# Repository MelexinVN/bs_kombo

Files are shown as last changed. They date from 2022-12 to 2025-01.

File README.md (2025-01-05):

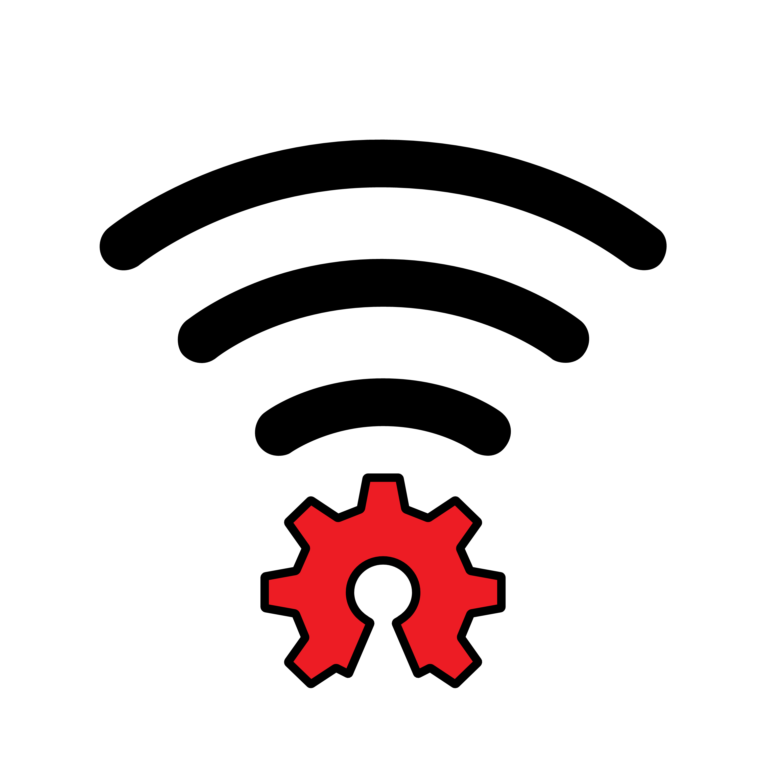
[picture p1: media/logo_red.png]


# Открытые системы беспроводной коммуникации "КомБО"

Беспроводные системы "КомБО" - проект с открытым программным и аппаратным обеспечением 
(Open source hardware)

# Open wireless communication systems "КомБО"

Wireless systems "КомБО" - a project with open software and hardware
(Open source hardware)

## Цели проекта
Целями проекта являются: разработка устройств беспроводной связи различного назначения и свободное распространение результатов этих разработок.

## Project goals
The goals of the project are: development of wireless communication devices for various purposes and free distribution of the results of these developments.

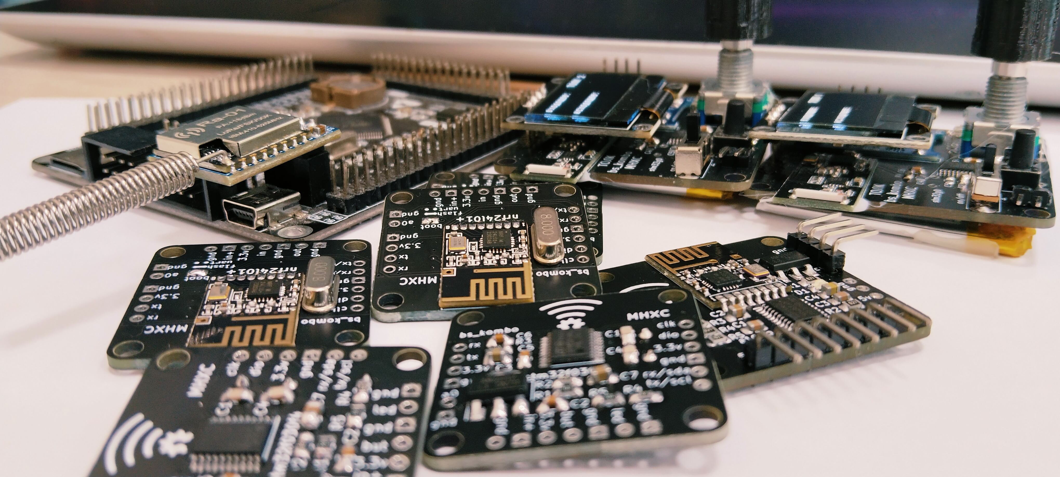
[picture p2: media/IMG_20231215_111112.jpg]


## Основные особенности проекта:
-	***Открытая лицензия***. Все материалы: исходники ПО, проекты печатных плат и 3д модели находятся в свободном доступе. 
-	***Доступные средства разработки***. Используются только бесплатные средства разработки, а также доступные материалы и компоненты.
-	***Подробная документация***. Исходники оформляются максимально подробно и документировано, чтобы их было легко изменить под свои цели. Причем документация преимущественно на русском языке (что, конечно, не принципиально, но для некоторых имеет решающее значение).

## Main features of the project:
- ***Open license***. All materials: software sources, printed circuit board designs and 3D models are freely available.
- ***Available development tools***. Only free development tools are used, as well as available materials and components.
- ***Detailed documentation***. Sources are drawn up in as much detail and documented as possible so that they can be easily changed to suit your purposes. Moreover, the documentation is predominantly in Russian (which, of course, is not essential, but for some it is of decisive importance).

## Прототипы
Ведущие и ведомое устройства собраны на микроконтроллерах ATmega8, ATmega88, ATmega328, STM32F030F4P6, ESP32 и модулях приемо-передатчика NRF24L01+. 
Программы написаны на языке СИ в средах Keil µVision v5, Microchip Studio, а также в среде Arduino IDE специально для платформы Arduino и ESP32.

## Prototypes
Master and slave devices are assembled on ATmega8, ATmega88, ATmega328, STM32F030F4P6, ESP32 microcontrollers and NRF24L01+ transceiver modules.
The programs are written in the SI language in the Keil µVision v5, Microchip Studio environments, as well as in the Arduino IDE specifically for the Arduino and ESP32 platforms.

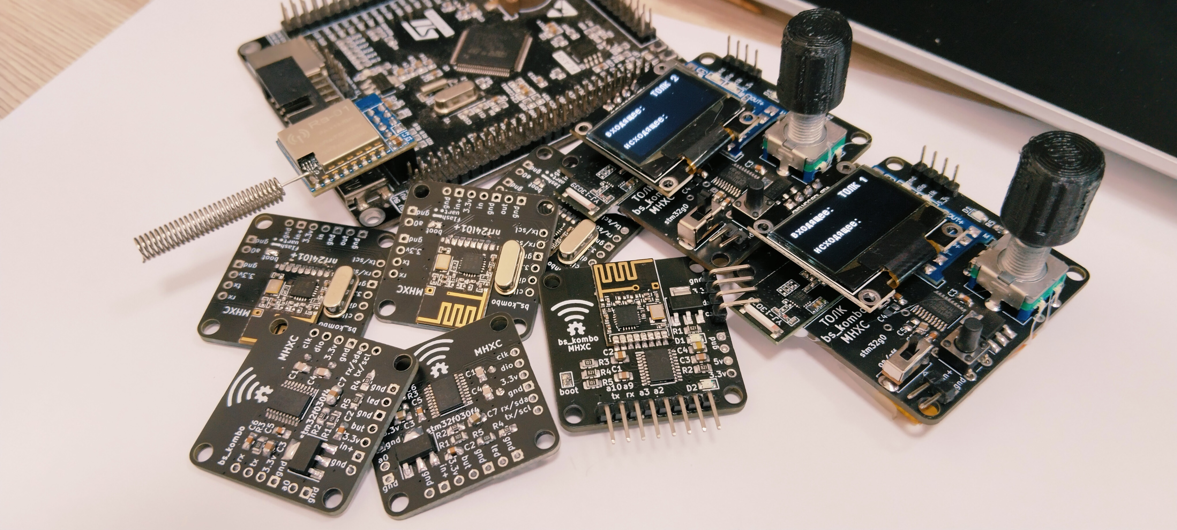
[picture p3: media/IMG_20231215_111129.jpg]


## Содержимое репозитория
### На данный момент в репозитории можно найти:

- исходники программ и исполняемые файлы прошивок устройств;
- исходники печатных плат (проекты в Kicad), а также гербер-файлы для заказа их изготовления;

### Планируется пополнять репозиторий:
- исходниками и STL-файлами новых 3D моделей корпусов;
- специальными программами верхнего уровня для связи с ведущим устройством;
- прошивками и печатными платами для новых исполнений и применений устройств.

## Repository content
### Currently in the repository you can find:

- program sources and executable firmware files for devices;
- sources of printed circuit boards (projects in Kicad), as well as gerber files for ordering their production;

### It is planned to update the repository:
- source codes and STL files of new 3D models of cases;
- special top-level programs for communication with the master device;
- firmware and printed circuit boards for new designs and applications of devices.

## Применения
Первое готовое и оформленное применение проекта - **СИДРУ**



**С**вето-

**И**злучающее

**Д**екоративное

**Р**адиоуправляемое

**У**стройство

Описание структуры, работы, а также все материалы можно найти в [соответствующем репозитории](https://github.com/MelexinVN/bs_kombo_sidru).



## Applications
The first ready and executed application of the project - **СИДРУ**

**Light Emitting Decorative Radio Controlled Device**

A description of the structure, operation, as well as all materials can be found in the [corresponding repository](https://github.com/MelexinVN/bs_kombo_sidru).

### Электронная почта: 		    [bskombo@yandex.ru](bskombo@yandex.ru)

### Социальные сети:

- паблик ВКонтакте: 			  [vk.com/bs_kombo](https://vk.com/bs_kombo)
- Telegram-канал: 	        [t.me/bskombo](https://t.me/bskombo)
- Telegram-чат: 	          [t.me/bs_kombo_chat](https://t.me/bs_kombo_chat)

### Email: [bskombo@yandex.ru](bskombo@yandex.ru)

### Social media:

- public VKontakte: [vk.com/bs_kombo](https://vk.com/bs_kombo)
- Telegram channel: [t.me/bskombo](https://t.me/bskombo)
- Telegram chat: [t.me/bs_kombo_chat](https://t.me/bs_kombo_chat)

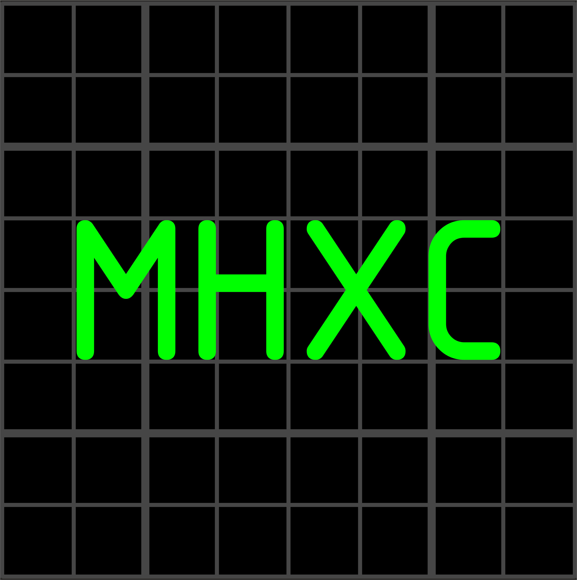
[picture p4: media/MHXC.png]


### Авторы всегда рады отзывам и любым конструктивным предложениям по улучшению проекта! 
### The authors are always happy to receive feedback and any constructive suggestions for improving the project!

## Лицензия
Проект распространяется под лицензией Creative Commons Attribution-ShareAlike 4.0 [CC BY-SA 4.0](https://creativecommons.org/licenses/by-sa/4.0/), 
а программное обеспечение - под лицензией GNU General Public License v3.0 [GPL-3.0 license](https://github.com/MelexinVN/bs_kombo/blob/main/LICENSE)

## License
This project is licensed under the Creative Commons 4.0 license with Attribution-ShareAlike [CC BY-SA 4.0](https://creativecommons.org/licenses/by-sa/4.0/), 
and the software is licensed under the GNU General Public License v3.0 [GPL-3.0 license](https://github.com/MelexinVN/bs_kombo/blob/main/LICENSE)

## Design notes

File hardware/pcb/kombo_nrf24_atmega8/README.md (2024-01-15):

### Плата для МК ATmega8/48/88/168/328 в корпусе TQFP-32 с модулем nrf24l01+ со штырьками.
### 2 слоя.
### Расположение монтажных отверстий сделано под существующие корпуса.

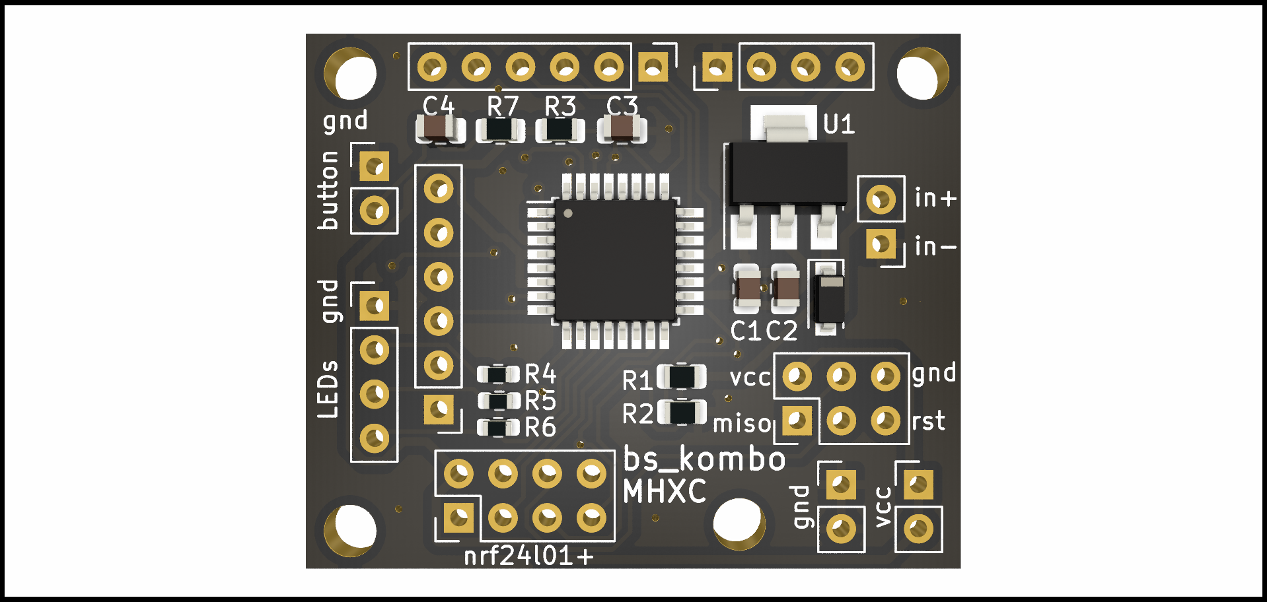
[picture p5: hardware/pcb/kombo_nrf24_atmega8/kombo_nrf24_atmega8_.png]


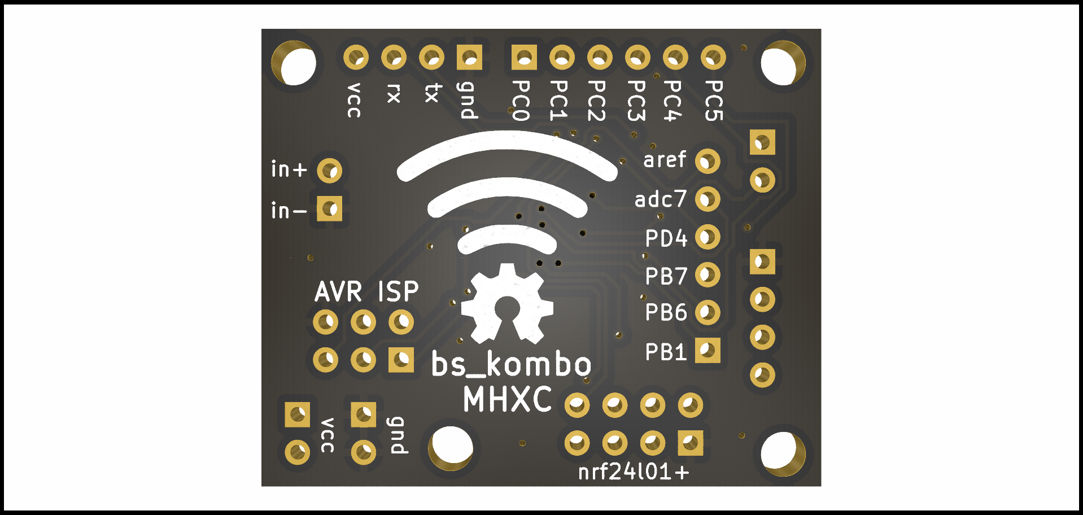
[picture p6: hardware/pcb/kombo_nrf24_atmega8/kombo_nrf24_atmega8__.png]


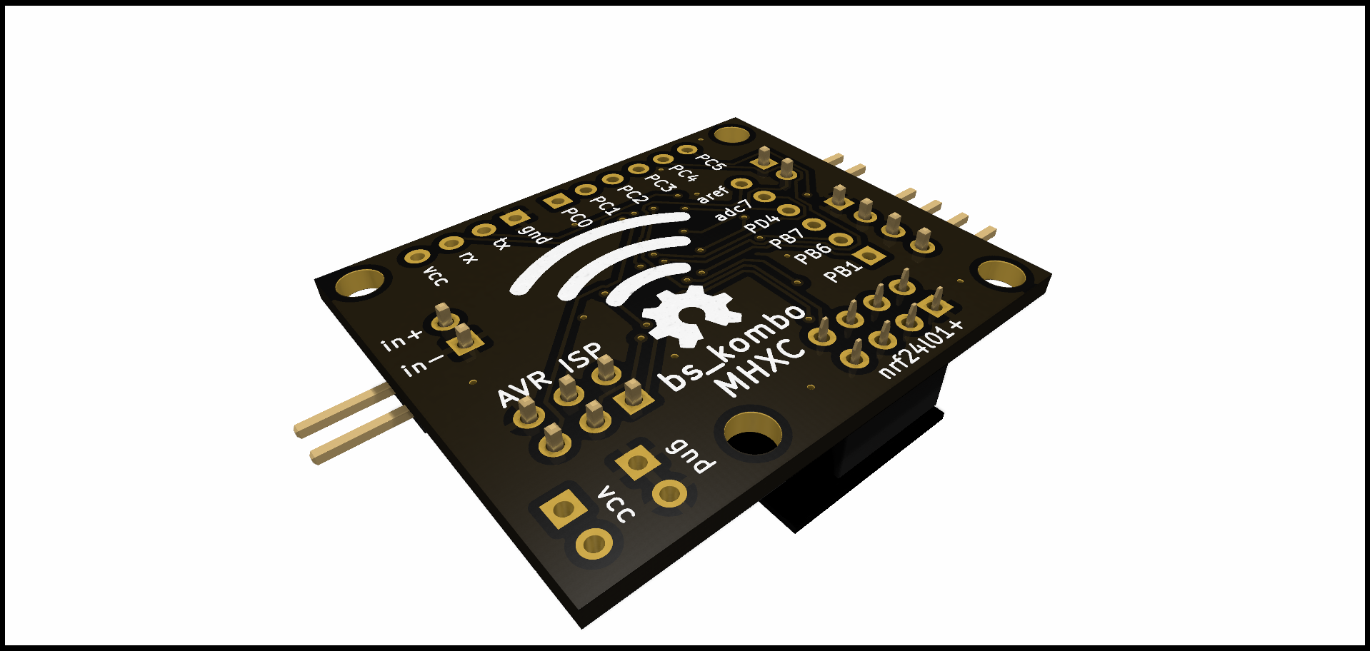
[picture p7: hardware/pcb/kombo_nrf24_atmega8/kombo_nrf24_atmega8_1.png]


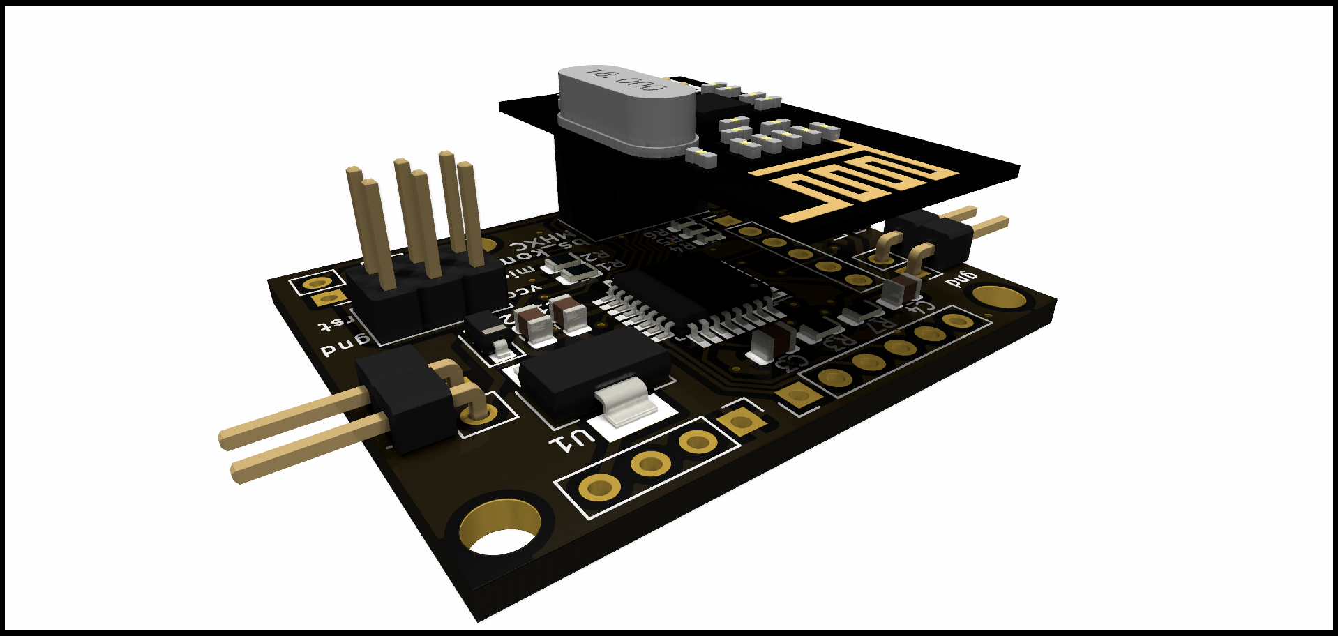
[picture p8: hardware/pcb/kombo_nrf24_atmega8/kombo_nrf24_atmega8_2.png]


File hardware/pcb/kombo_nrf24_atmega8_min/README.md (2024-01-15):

### Плата для МК ATmega8/48/88/168/328 в корпусе TQFP-32 с модулем nrf24l01+ со штырьками.
### Два слоя. Без монтажных отверстий, минимальные габариты - по размеру модуля nrf24l01 в со штырьками.

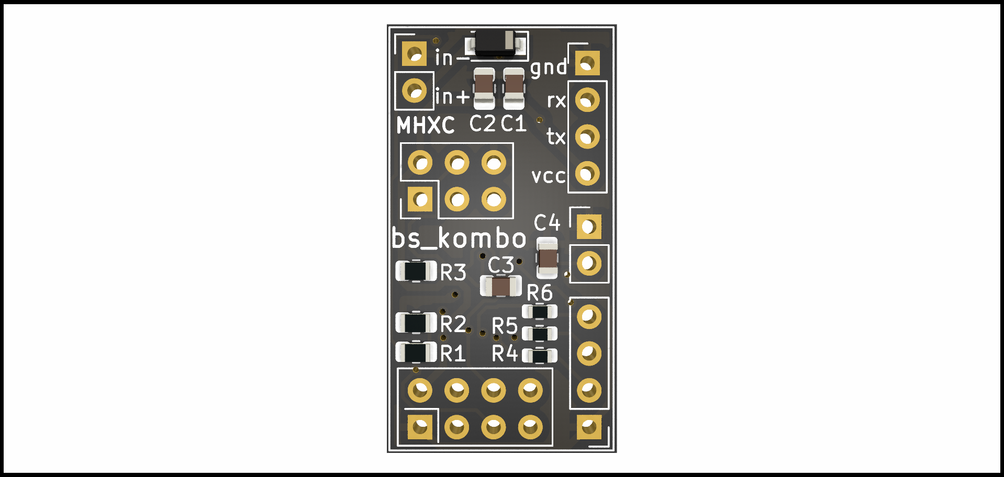
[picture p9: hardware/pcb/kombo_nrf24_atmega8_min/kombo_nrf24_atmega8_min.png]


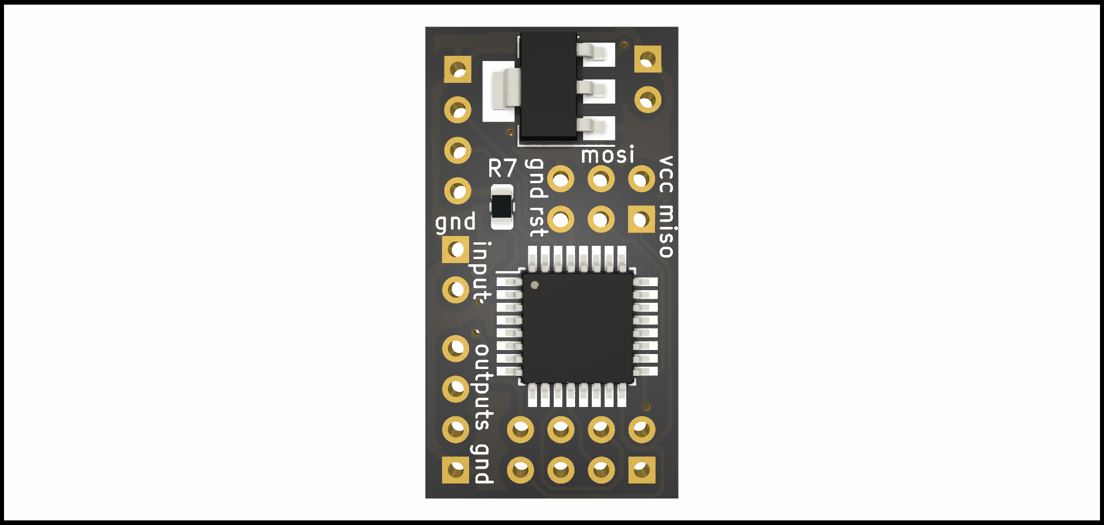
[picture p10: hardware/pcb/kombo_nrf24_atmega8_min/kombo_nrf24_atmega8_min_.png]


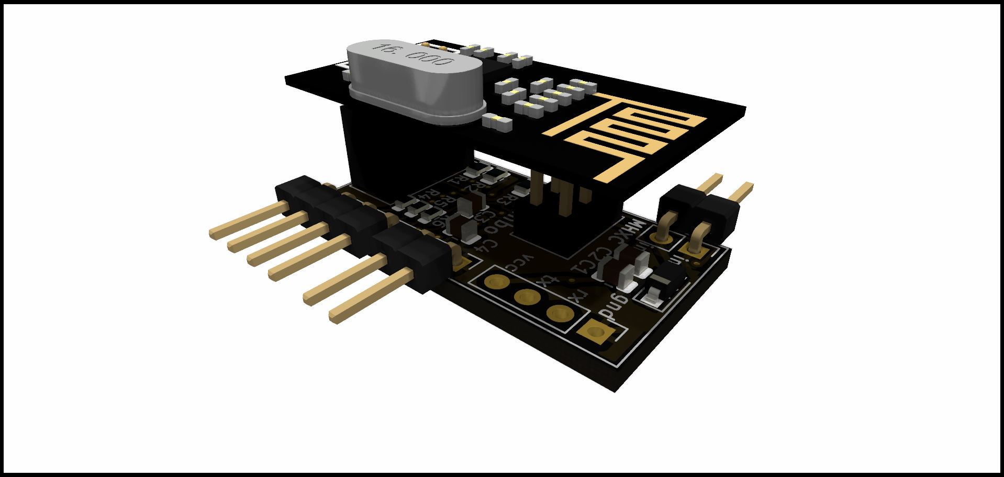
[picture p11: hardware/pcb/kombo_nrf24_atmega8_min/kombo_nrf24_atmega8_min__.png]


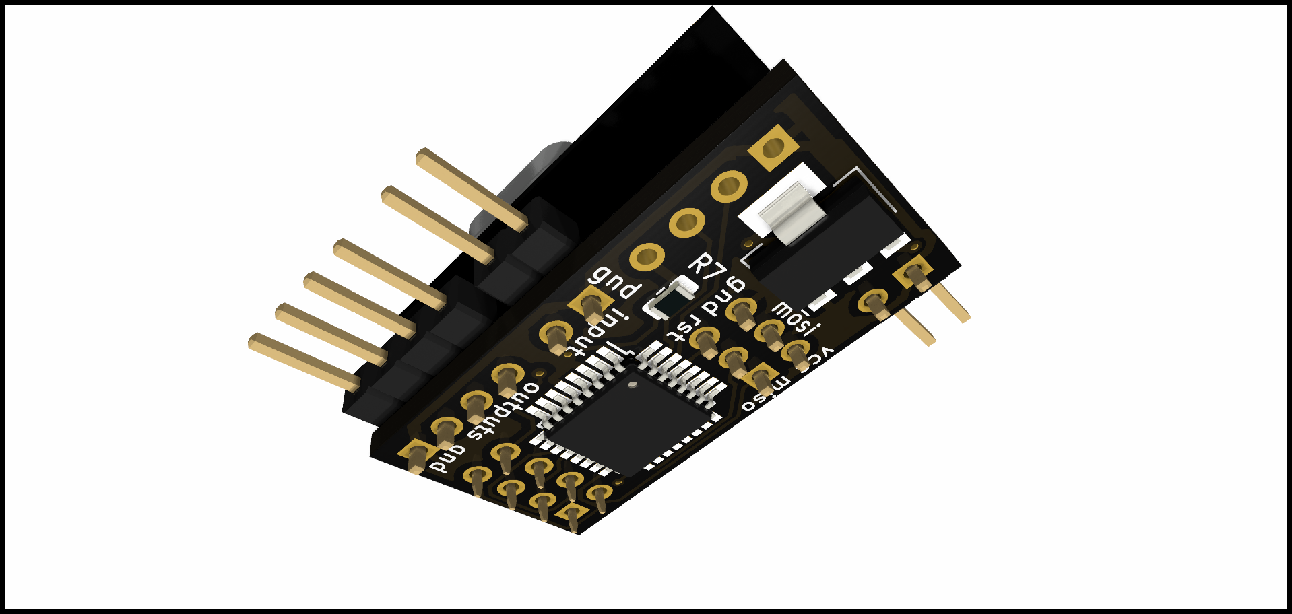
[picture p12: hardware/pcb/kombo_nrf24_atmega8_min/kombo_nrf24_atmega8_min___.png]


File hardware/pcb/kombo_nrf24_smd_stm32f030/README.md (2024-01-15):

### Плата для МК stm32f030f4p6 в корпусе TSSOP-20 с модулем nrf24l01+ в smd исполнении.

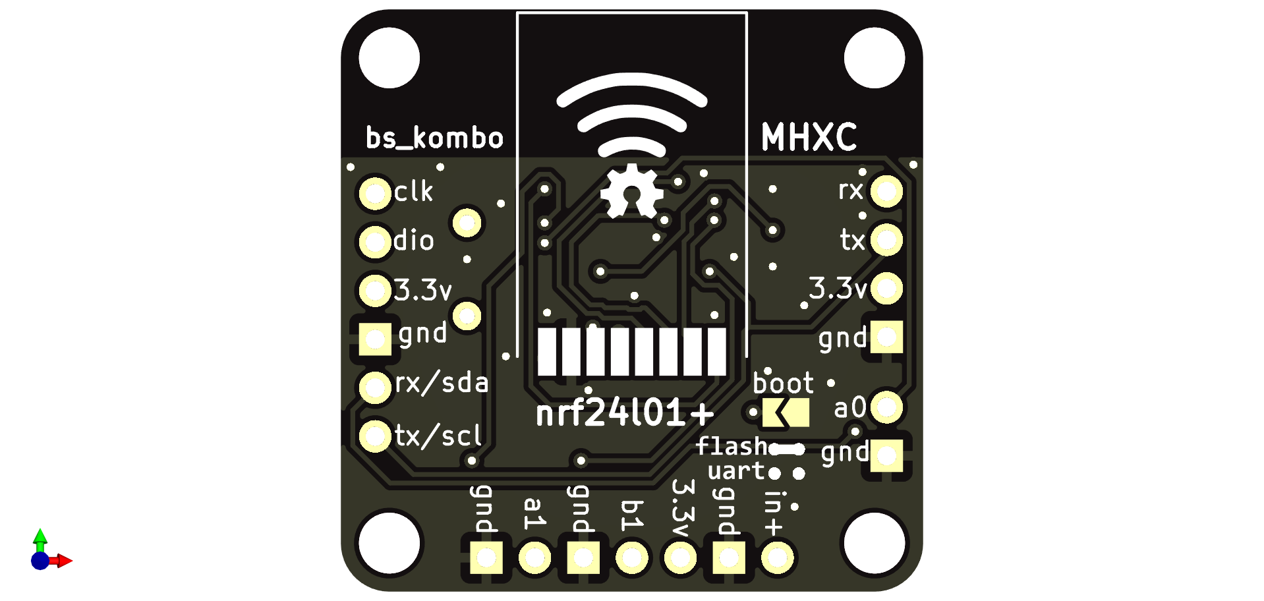
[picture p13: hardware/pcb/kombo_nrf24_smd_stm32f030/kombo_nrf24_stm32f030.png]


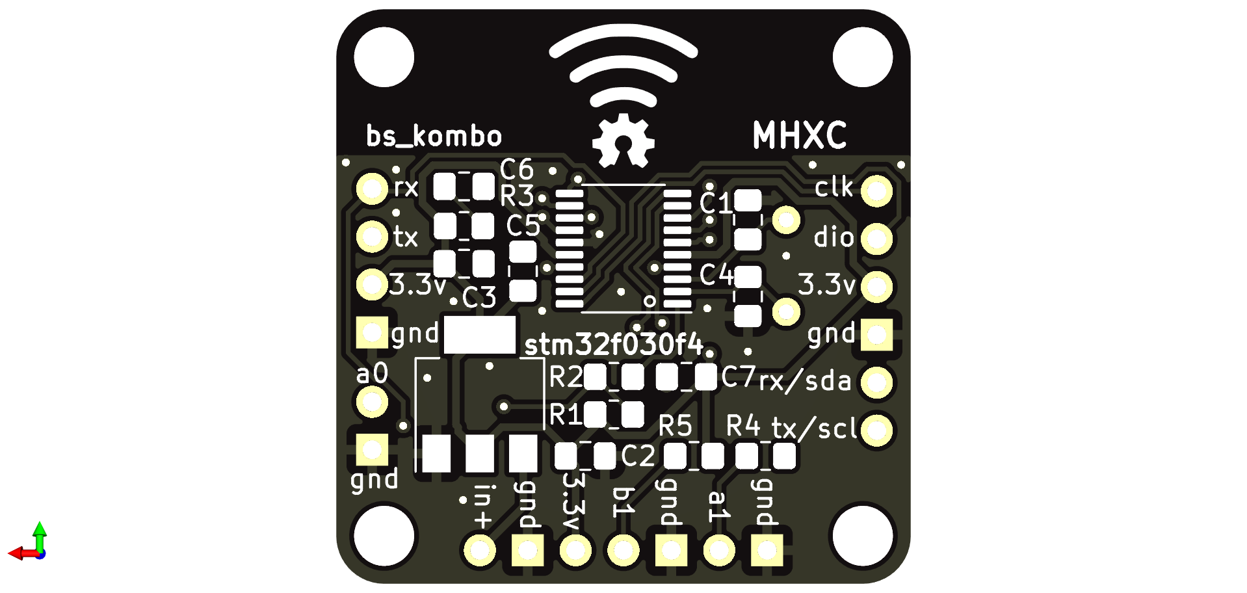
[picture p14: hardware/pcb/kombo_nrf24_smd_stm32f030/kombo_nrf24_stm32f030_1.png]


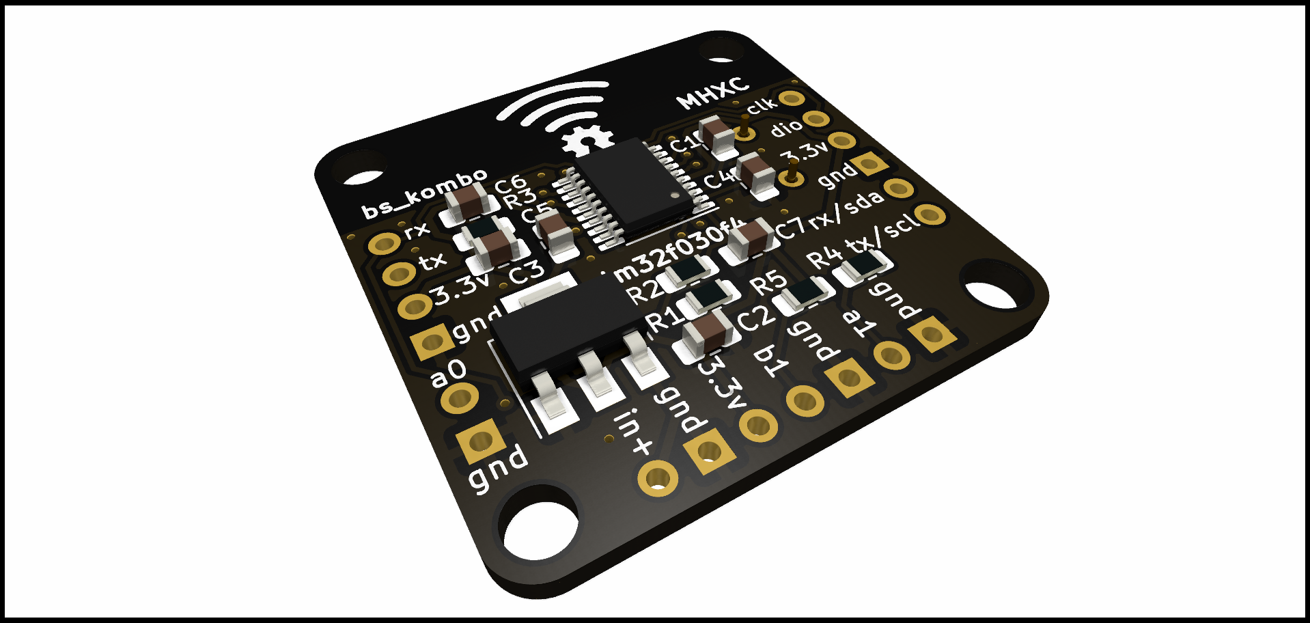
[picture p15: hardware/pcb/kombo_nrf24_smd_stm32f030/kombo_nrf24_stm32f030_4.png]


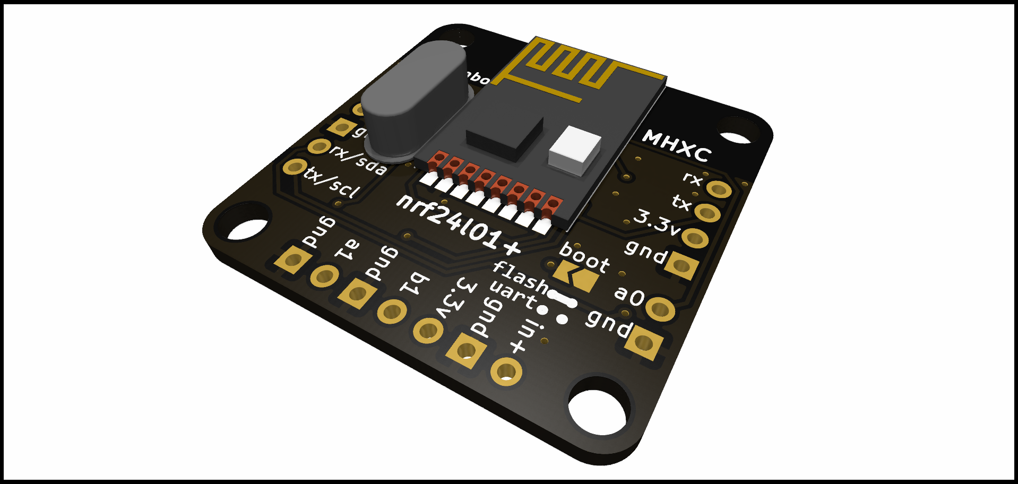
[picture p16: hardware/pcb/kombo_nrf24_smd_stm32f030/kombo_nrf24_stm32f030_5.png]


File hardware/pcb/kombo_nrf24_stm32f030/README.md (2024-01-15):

### Плата для МК stm32f030f4p6 в корпусе TSSOP-20 с модулем nrf24l01+ со штырьками.

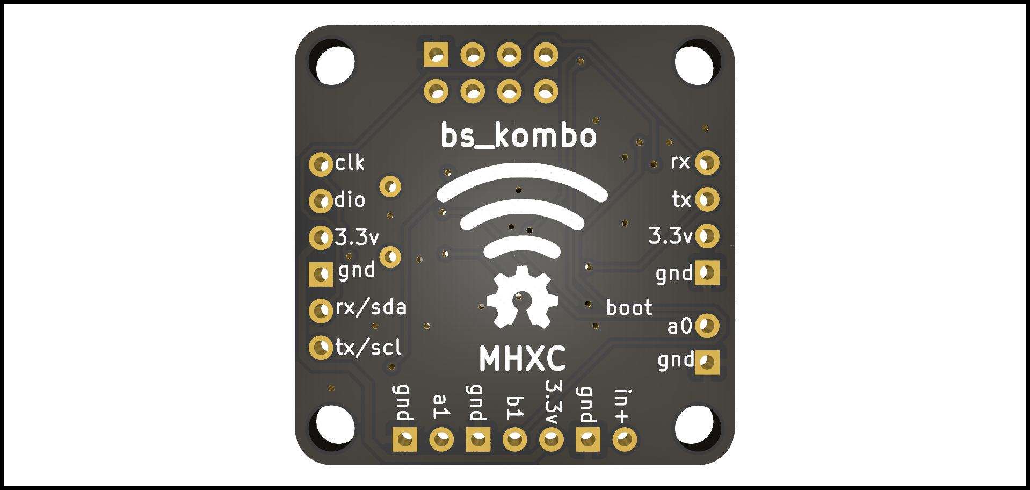
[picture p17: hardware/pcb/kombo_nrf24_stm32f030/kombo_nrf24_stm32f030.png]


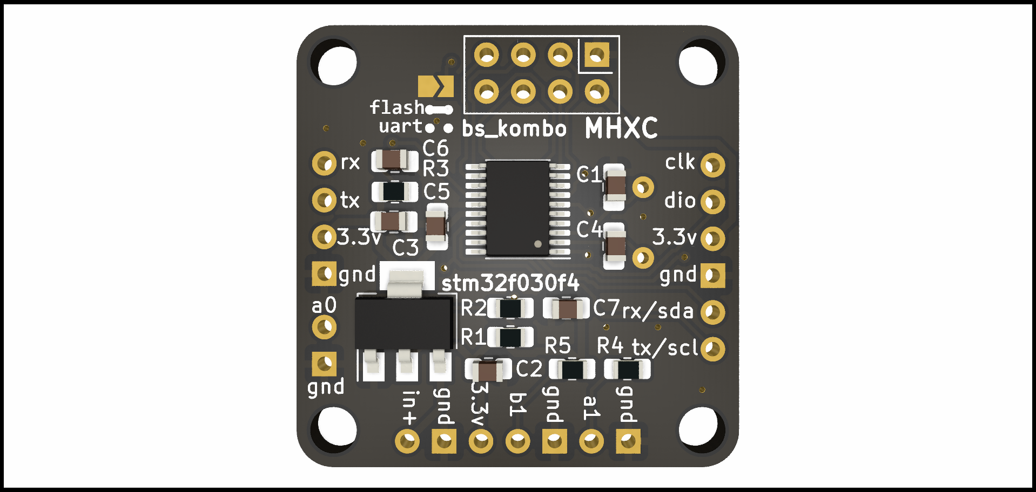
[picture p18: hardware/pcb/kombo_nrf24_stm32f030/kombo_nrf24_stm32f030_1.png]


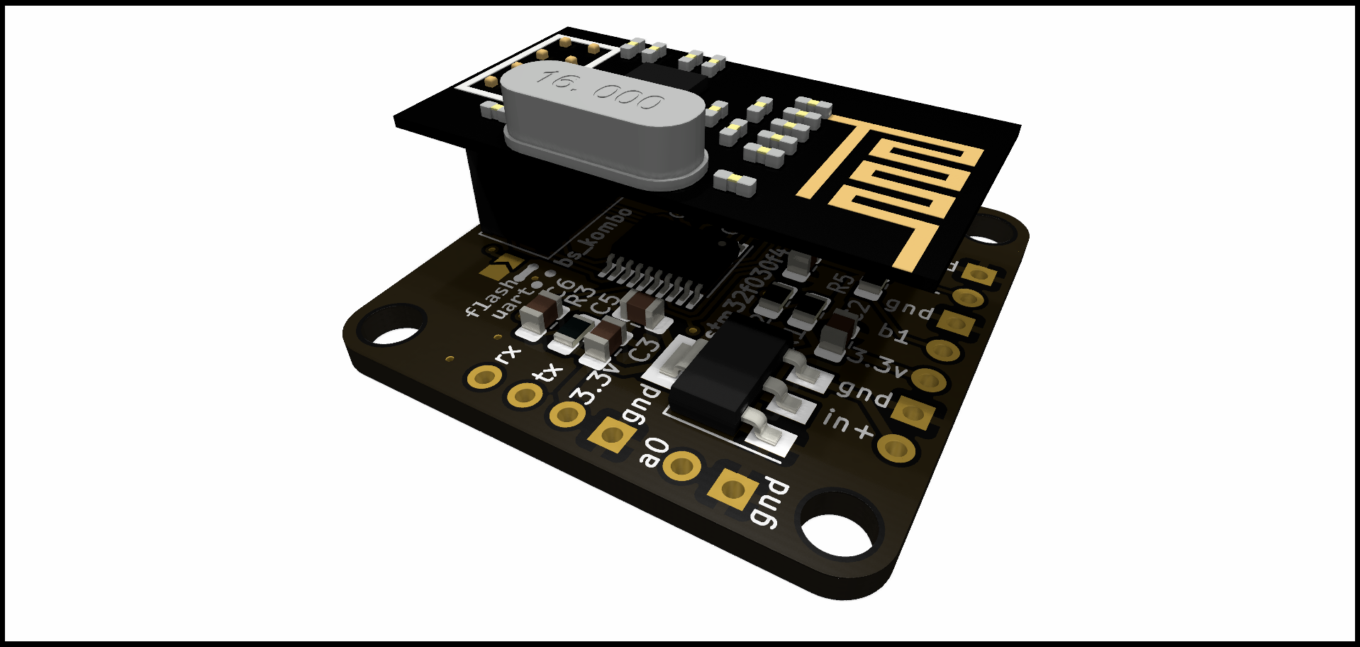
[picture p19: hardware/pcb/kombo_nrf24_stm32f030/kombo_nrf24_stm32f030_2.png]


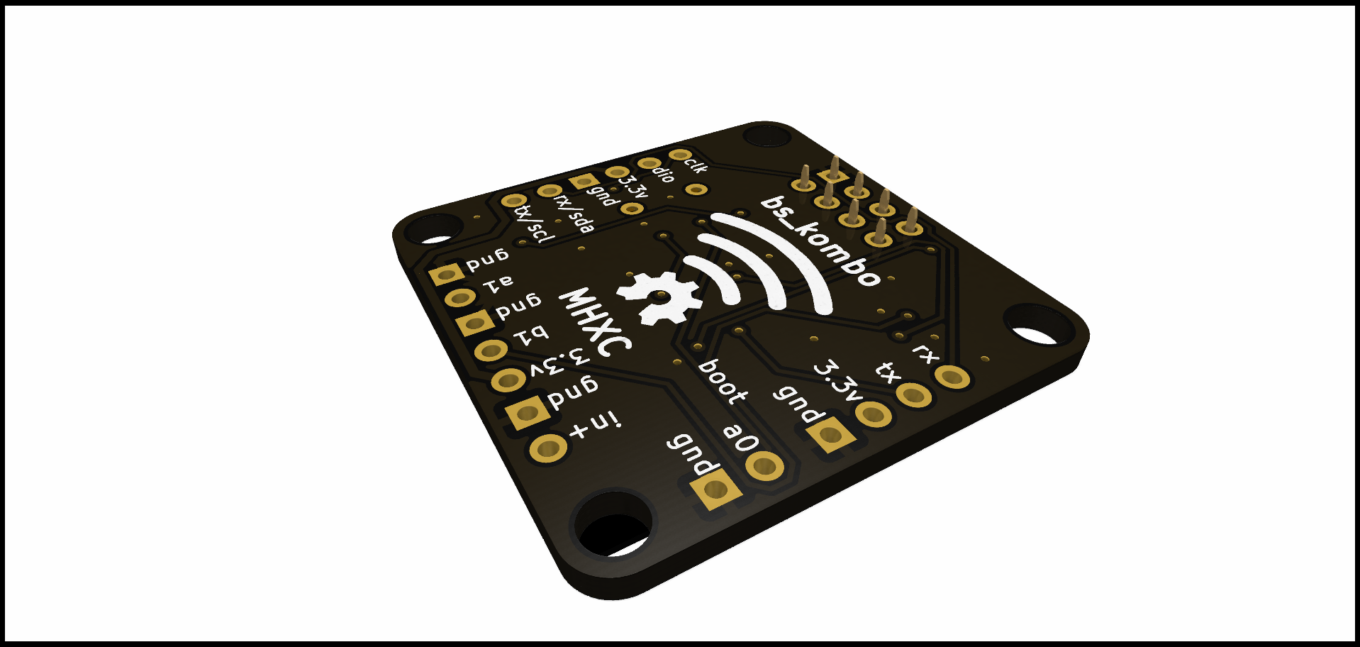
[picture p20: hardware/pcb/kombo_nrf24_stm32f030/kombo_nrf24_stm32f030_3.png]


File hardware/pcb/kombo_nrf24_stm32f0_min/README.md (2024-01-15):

### Плата для МК stm32f030f4p6 в корпусе TSSOP-20 с модулем nrf24l01+ со штырьками.
### Два слоя. Без монтажных отверстий, минимальные габариты - по размеру модуля nrf24l01 в со штырьками.

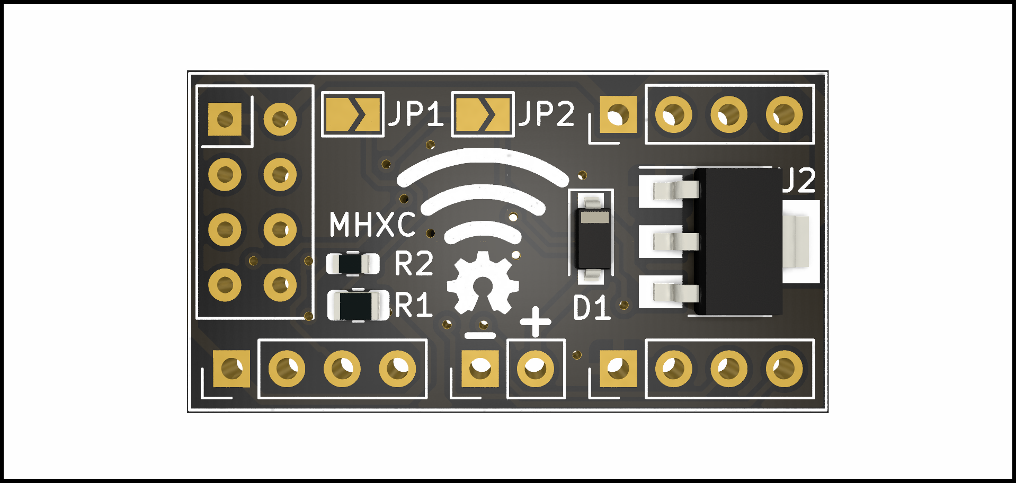
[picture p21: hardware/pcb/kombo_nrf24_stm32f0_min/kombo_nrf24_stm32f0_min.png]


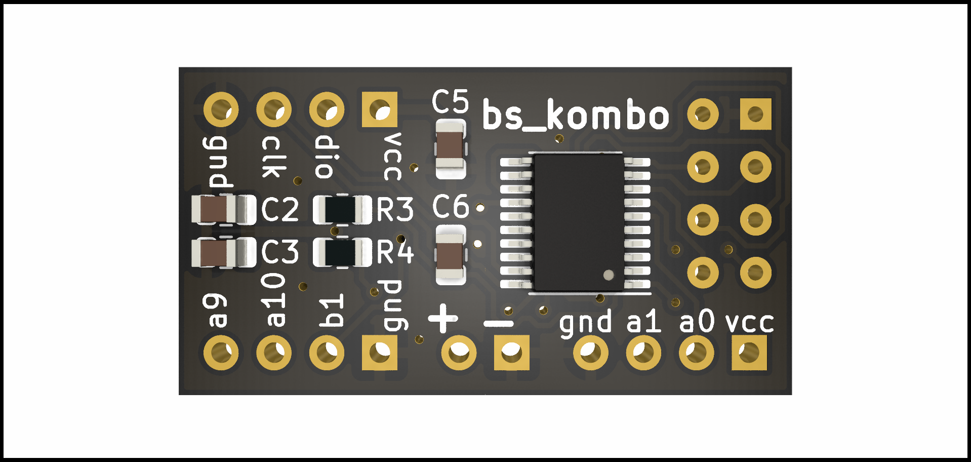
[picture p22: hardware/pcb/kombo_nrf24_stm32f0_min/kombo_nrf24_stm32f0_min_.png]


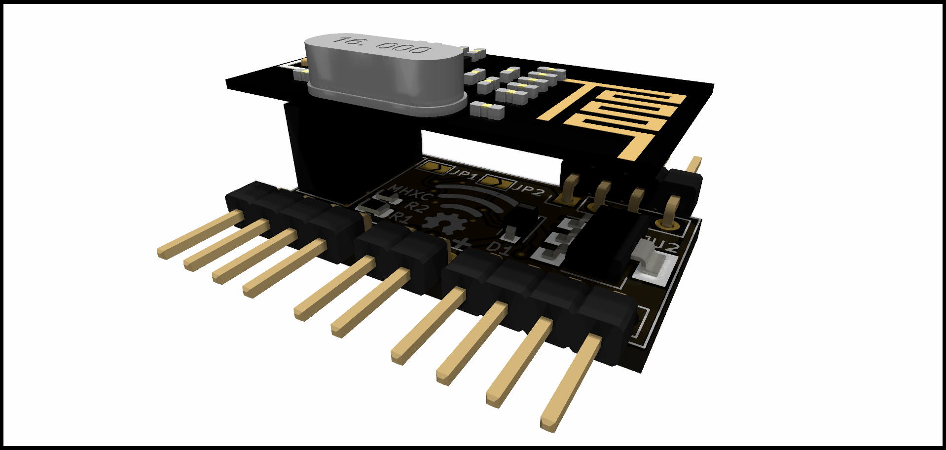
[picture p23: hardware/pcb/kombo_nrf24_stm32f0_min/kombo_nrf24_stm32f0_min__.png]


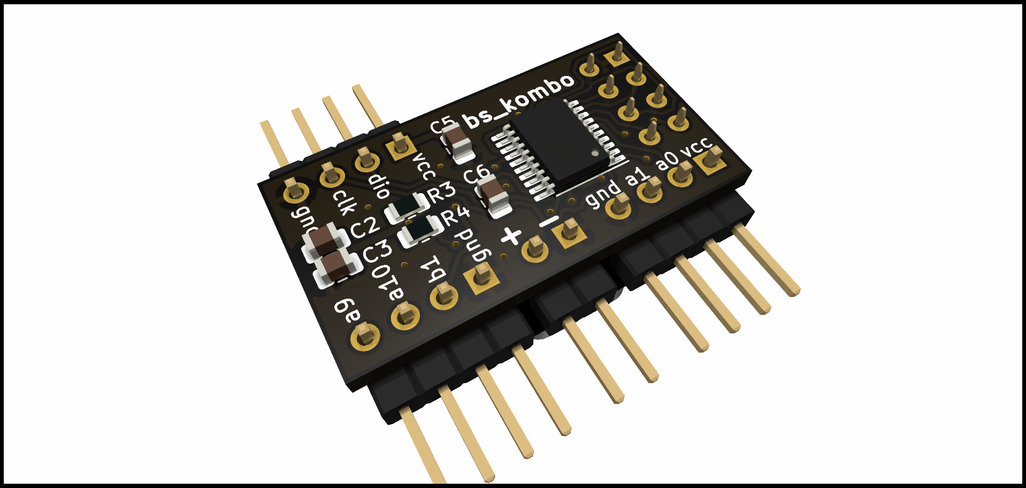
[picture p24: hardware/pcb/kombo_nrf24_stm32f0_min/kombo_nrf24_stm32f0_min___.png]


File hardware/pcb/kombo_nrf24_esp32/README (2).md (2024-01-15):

### Плата для ESP32-WROOM с smd модулем nrf24l01+.
### Для перевода в режим загрузки прошивки нажать кнопку "EN" и отпустить при зажатой кнопке "BOOT", либо подать питание при зажатой кнопке "BOOT".

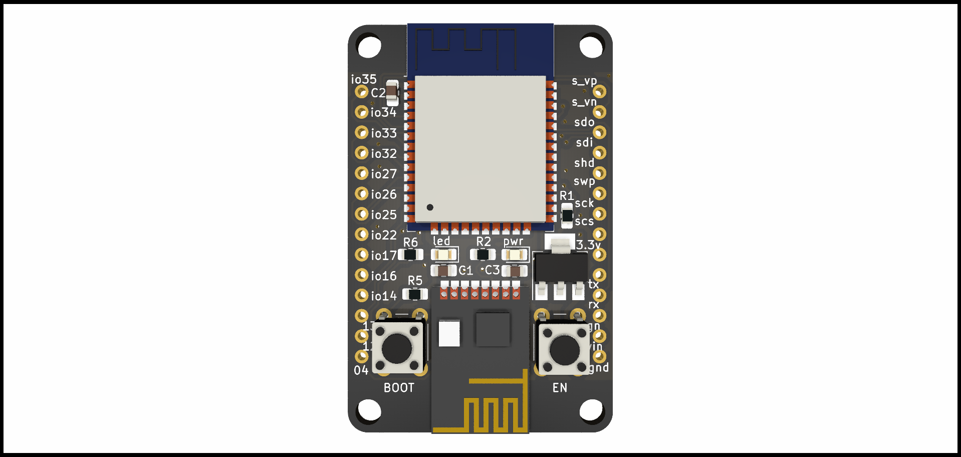
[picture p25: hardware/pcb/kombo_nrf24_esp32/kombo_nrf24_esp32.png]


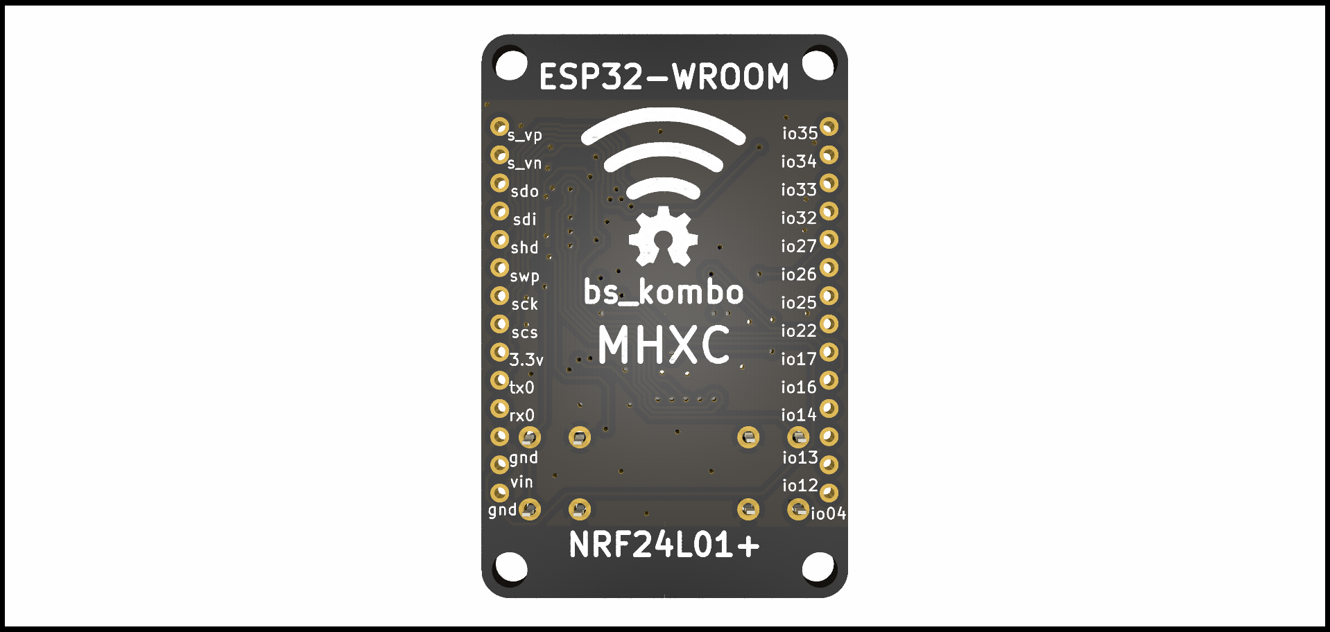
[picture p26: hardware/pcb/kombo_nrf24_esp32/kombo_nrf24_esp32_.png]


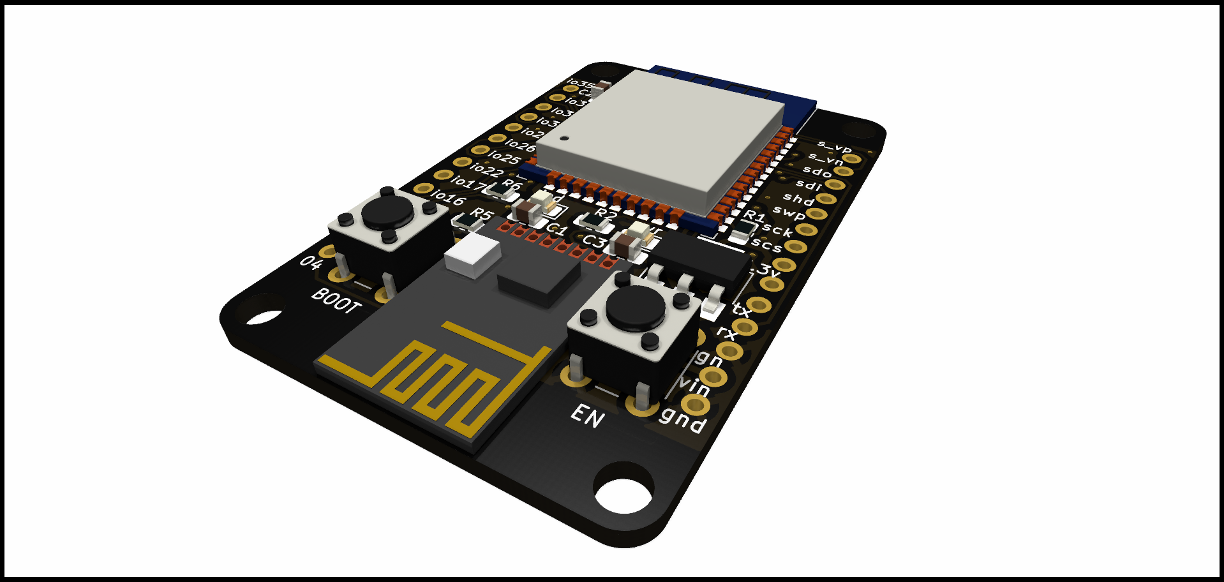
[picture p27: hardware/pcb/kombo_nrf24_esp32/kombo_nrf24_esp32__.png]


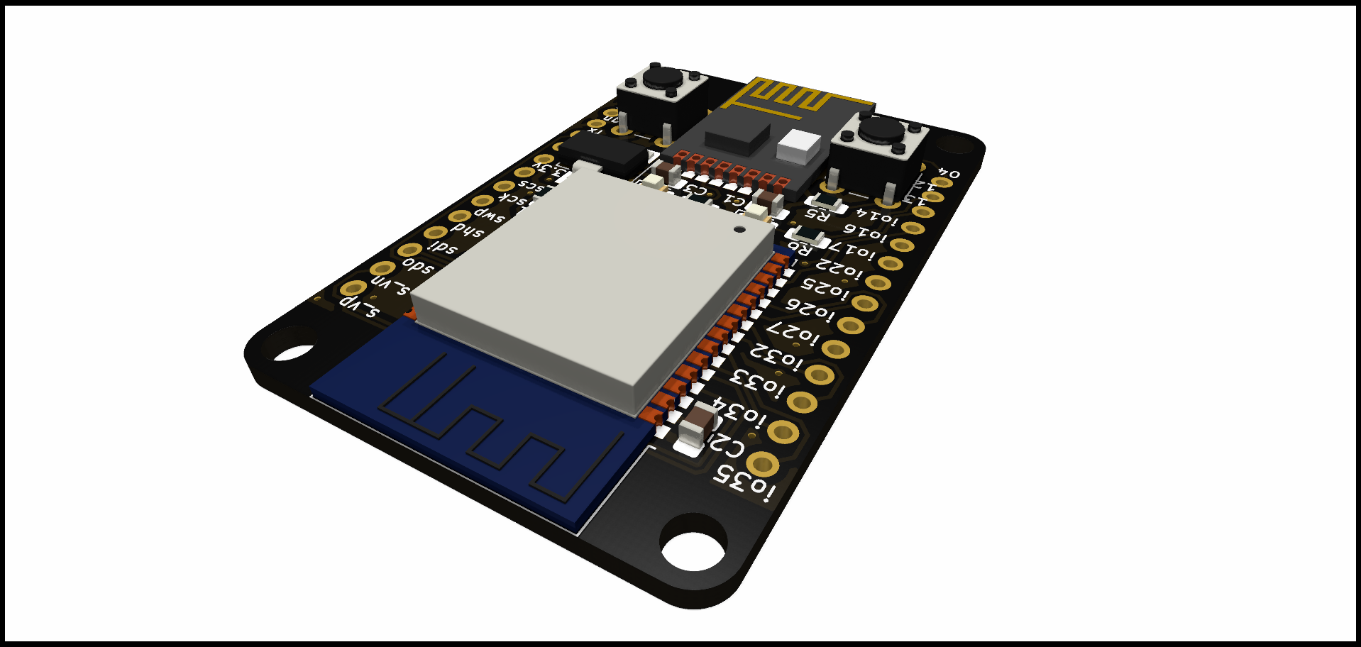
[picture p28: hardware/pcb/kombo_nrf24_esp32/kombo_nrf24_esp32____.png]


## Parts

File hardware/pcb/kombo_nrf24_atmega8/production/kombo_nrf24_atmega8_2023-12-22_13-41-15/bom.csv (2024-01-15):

Designator | Footprint | Quantity | Value | LCSC Part #
C1, C3, C4 | 0805 | 3 | 100n
C2 | 0805 | 1 | 10u
D1 | D_SOD-123 | 1 | 1N4148W
J1, J7, J8, J9 | PinHeader_1x02_P2.54mm_Vertical | 4 | Conn_01x02
J2, J4 | PinHeader_1x06_P2.54mm_Vertical | 2 | Conn_01x06
J3 | PinHeader_2x03_P2.54mm_Vertical | 1 | AVR-ISP-6
J5, J6 | PinHeader_1x04_P2.54mm_Vertical | 2 | Conn_01x04
R1, R2 | 0805 | 2 | 4,7k
R3, R7 | 0805 | 2 | 10k
R4, R5, R6 | 0603 | 3 | 620
U1 | SOT-223-3_TabPin2 | 1 | AMS1117-3.3
U2 | TQFP-32_7x7mm_P0.8mm | 1 | ATmega8A-A
U3 | PinHeader_2x04_P2.54mm_Vertical | 1 | NRF24L01_Breakout

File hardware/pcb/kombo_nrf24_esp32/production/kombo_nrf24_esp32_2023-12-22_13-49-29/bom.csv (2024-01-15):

Designator | Footprint | Quantity | Value | LCSC Part #
C1 | 0805 | 1 | 100n
C2, C3 | 0805 | 2 | 10u
D1, D2 | 0805 | 2 | LED
J1 | PinHeader_1x02_P2.54mm_Vertical | 1 | Conn_01x02
J2 | PinHeader_1x08_P2.54mm_Vertical | 1 | Conn_01x08
J3 | PinHeader_1x04_P2.54mm_Vertical | 1 | Conn_01x04
J4 | PinHeader_1x14_P2.54mm_Vertical | 1 | Conn_01x14
R1, R5 | 0805 | 2 | 10К
R2, R6 | 0805 | 2 | 620
SW1, SW2 | SW_PUSH_6mm_H4.3mm | 2 | SW_Push_Dual_x2
U1 | SOT-223-3_TabPin2 | 1 | AMS1117-3.3
U2 | ESP32-WROOM-32 | 1 | ESP32-WROOM-32
U3 | NRF24L01-SMD | 1 | NRF24L01_Breakout

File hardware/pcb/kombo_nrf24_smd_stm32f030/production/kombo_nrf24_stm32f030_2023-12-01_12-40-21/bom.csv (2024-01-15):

Designator | Footprint | Quantity | Value | LCSC Part #
C1, C4 | 0805 | 2 | 22p
C2, C5, C6 | 0805 | 3 | 100n
C3, C7 | 0805 | 2 | 10u
J1 | PinHeader_1x07_P2.54mm_Vertical | 1 | Conn_01x07
J2 | PinHeader_1x04_P2.54mm_Vertical | 1 | Conn_01x04
J3 | PinHeader_1x06_P2.54mm_Vertical | 1 | Conn_01x06
J4 | PinHeader_1x02_P2.54mm_Vertical | 1 | Conn_01x02
JP1 | SolderJumper-2_P1.3mm_Open_TrianglePad1.0x1.5mm | 1 | SolderJumper_2_Open
R1, R3, R5 | 0805 | 3 | 10k
R2, R4 | 0805 | 2 | 620
U1 | NRF24L01-Module-SMD | 1 | NRF24L01_Breakout
U2 | SOT-223-3_TabPin2 | 1 | AMS1117-3.3
U3 | TSSOP-20_4.4x6.5mm_P0.65mm | 1 | STM32F030F4Px
Y1 | Crystal_HC49-U_Vertical | 1 | Crystal

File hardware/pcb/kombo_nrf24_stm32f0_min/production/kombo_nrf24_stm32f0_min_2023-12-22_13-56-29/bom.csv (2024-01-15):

Designator | Footprint | Quantity | Value | LCSC Part #
C2, C5, C6 | 0805 | 3 | 100n
C3 | 0805 | 1 | 10u
D1 | D_SOD-123 | 1 | 1N4148W
J1 | PinHeader_1x02_P2.54mm_Vertical | 1 | Conn_01x02
J2, J3, J4 | PinHeader_1x04_P2.54mm_Vertical | 3 | Conn_01x04
JP1, JP2 | SolderJumper-2_P1.3mm_Open_TrianglePad1.0x1.5mm | 2 | SolderJumper_2_Open
R1, R3 | 0805 | 2 | 10k
R2 | 0603 | 1 | 620
R4 | 0805 | 1 | 4,7k
U1 | nRF24L01_Breakout | 1 | NRF24L01_Breakout
U2 | SOT-223-3_TabPin2 | 1 | AMS1117-3.3
U3 | TSSOP-20_4.4x6.5mm_P0.65mm | 1 | STM32F030F4Px

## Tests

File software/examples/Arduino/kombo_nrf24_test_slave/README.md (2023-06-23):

## Пример создан в версии Arduino IDE v.2.0.3

### Вариант подключения:

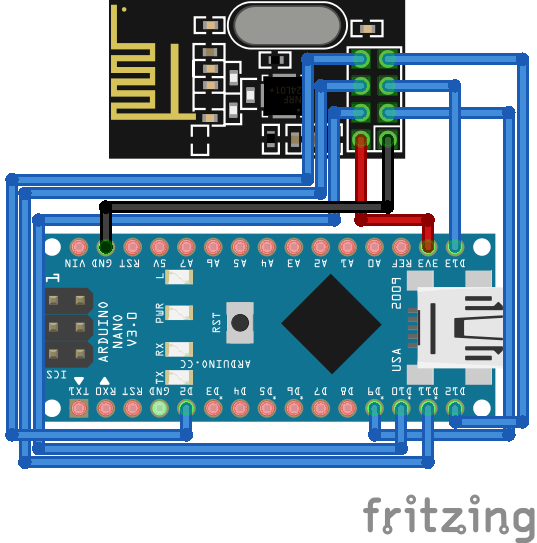
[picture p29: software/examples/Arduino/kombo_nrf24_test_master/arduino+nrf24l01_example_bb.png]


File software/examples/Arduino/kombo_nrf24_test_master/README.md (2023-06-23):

## Пример создан в версии Arduino IDE v.2.1.0

### Вариант подключения:



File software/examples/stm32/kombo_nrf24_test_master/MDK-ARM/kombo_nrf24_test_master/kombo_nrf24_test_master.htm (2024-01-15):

# Static Call Graph for image kombo_nrf24_test_master\kombo_nrf24_test_master.axf

#<CALLGRAPH># ARM Linker, 6190004: Last Updated: Thu Dec 21 12:55:21 2023

### Maximum Stack Usage = 272 bytes + Unknown(Functions without stacksize, Cycles, Untraceable Function Pointers)

### Call chain for Maximum Stack Depth:

__rt_entry_main ⇒ main ⇒ nrf24l01_receive ⇒ __2sprintf ⇒ _printf_char_common ⇒ __printf

### Functions with no stack information

- __user_initial_stackheap

### Mutually Recursive functions

- ADC1_IRQHandler ⇒ ADC1_IRQHandler
- HardFault_Handler ⇒ HardFault_Handler
- NMI_Handler ⇒ NMI_Handler

### Function Pointers

- ADC1_IRQHandler from startup_stm32f030x6.o(.text) referenced from startup_stm32f030x6.o(RESET)
- DMA1_Channel1_IRQHandler from startup_stm32f030x6.o(.text) referenced from startup_stm32f030x6.o(RESET)
- DMA1_Channel2_3_IRQHandler from startup_stm32f030x6.o(.text) referenced from startup_stm32f030x6.o(RESET)
- DMA1_Channel4_5_IRQHandler from startup_stm32f030x6.o(.text) referenced from startup_stm32f030x6.o(RESET)
- EXTI0_1_IRQHandler from startup_stm32f030x6.o(.text) referenced from startup_stm32f030x6.o(RESET)
- EXTI2_3_IRQHandler from stm32f0xx_it.o(.text.EXTI2_3_IRQHandler) referenced from startup_stm32f030x6.o(RESET)
- EXTI4_15_IRQHandler from startup_stm32f030x6.o(.text) referenced from startup_stm32f030x6.o(RESET)
- FLASH_IRQHandler from startup_stm32f030x6.o(.text) referenced from startup_stm32f030x6.o(RESET)
- HardFault_Handler from stm32f0xx_it.o(.text.HardFault_Handler) referenced from startup_stm32f030x6.o(RESET)
- I2C1_IRQHandler from startup_stm32f030x6.o(.text) referenced from startup_stm32f030x6.o(RESET)
- NMI_Handler from stm32f0xx_it.o(.text.NMI_Handler) referenced from startup_stm32f030x6.o(RESET)
- PendSV_Handler from stm32f0xx_it.o(.text.PendSV_Handler) referenced from startup_stm32f030x6.o(RESET)
- RCC_IRQHandler from startup_stm32f030x6.o(.text) referenced from startup_stm32f030x6.o(RESET)
- RTC_IRQHandler from startup_stm32f030x6.o(.text) referenced from startup_stm32f030x6.o(RESET)
- Reset_Handler from startup_stm32f030x6.o(.text) referenced from startup_stm32f030x6.o(RESET)
- SPI1_IRQHandler from startup_stm32f030x6.o(.text) referenced from startup_stm32f030x6.o(RESET)
- SVC_Handler from stm32f0xx_it.o(.text.SVC_Handler) referenced from startup_stm32f030x6.o(RESET)
- SysTick_Handler from stm32f0xx_it.o(.text.SysTick_Handler) referenced from startup_stm32f030x6.o(RESET)
- SystemInit from system_stm32f0xx.o(.text.SystemInit) referenced from startup_stm32f030x6.o(.text)
- TIM14_IRQHandler from startup_stm32f030x6.o(.text) referenced from startup_stm32f030x6.o(RESET)
- TIM16_IRQHandler from startup_stm32f030x6.o(.text) referenced from startup_stm32f030x6.o(RESET)
- TIM17_IRQHandler from startup_stm32f030x6.o(.text) referenced from startup_stm32f030x6.o(RESET)
- TIM1_BRK_UP_TRG_COM_IRQHandler from startup_stm32f030x6.o(.text) referenced from startup_stm32f030x6.o(RESET)
- TIM1_CC_IRQHandler from stm32f0xx_it.o(.text.TIM1_CC_IRQHandler) referenced from startup_stm32f030x6.o(RESET)
- TIM3_IRQHandler from startup_stm32f030x6.o(.text) referenced from startup_stm32f030x6.o(RESET)
- USART1_IRQHandler from startup_stm32f030x6.o(.text) referenced from startup_stm32f030x6.o(RESET)
- WWDG_IRQHandler from startup_stm32f030x6.o(.text) referenced from startup_stm32f030x6.o(RESET)
- __main from __main.o(!!!main) referenced from startup_stm32f030x6.o(.text)
- _printf_input_char from _printf_char_common.o(.text) referenced from _printf_char_common.o(.text)
- _sputc from _sputc.o(.text) referenced from noretval__2sprintf.o(.text)

### Global Symbols

__main (Thumb, 8 bytes, Stack size 0 bytes, __main.o(!!!main))

[Calls]

- >> __rt_entry
- >> __scatterload

[Address Reference Count : 1]

- startup_stm32f030x6.o(.text)

__scatterload (Thumb, 0 bytes, Stack size unknown bytes, __scatter.o(!!!scatter))

[Called By]

- >> __main

__scatterload_rt2 (Thumb, 52 bytes, Stack size unknown bytes, __scatter.o(!!!scatter), UNUSED)

[Calls]

- >> __rt_entry

__scatterload_rt2_thumb_only (Thumb, 0 bytes, Stack size unknown bytes, __scatter.o(!!!scatter), UNUSED)

__scatterload_null (Thumb, 0 bytes, Stack size unknown bytes, __scatter.o(!!!scatter), UNUSED)

__scatterload_copy (Thumb, 26 bytes, Stack size unknown bytes, __scatter_copy.o(!!handler_copy), UNUSED)

[Calls]

- >> __scatterload_copy

[Called By]

- >> __scatterload_copy

__scatterload_zeroinit (Thumb, 28 bytes, Stack size unknown bytes, __scatter_zi.o(!!handler_zi), UNUSED)

_printf_percent (Thumb, 0 bytes, Stack size unknown bytes, _printf_percent.o(.ARM.Collect$$_printf_percent$$00000000))

[Called By]

- >> __printf

_printf_d (Thumb, 0 bytes, Stack size unknown bytes, _printf_d.o(.ARM.Collect$$_printf_percent$$00000009))

[Stack]

- Max Depth = 88 + Unknown Stack Size
- Call Chain = _printf_d ⇒ _printf_int_dec ⇒ _printf_int_common ⇒ _printf_post_padding

[Calls]

- >> _printf_x
- >> _printf_int_dec

_printf_x (Thumb, 0 bytes, Stack size unknown bytes, _printf_x.o(.ARM.Collect$$_printf_percent$$0000000C))

[Stack]

- Max Depth = 72 + Unknown Stack Size
- Call Chain = _printf_x ⇒ _printf_int_hex ⇒ _printf_int_common ⇒ _printf_post_padding

[Calls]

- >> _printf_percent_end
- >> _printf_int_hex

[Called By]

- >> _printf_d

_printf_percent_end (Thumb, 0 bytes, Stack size unknown bytes, _printf_percent_end.o(.ARM.Collect$$_printf_percent$$00000017))

[Called By]

- >> _printf_x

__rt_lib_init (Thumb, 0 bytes, Stack size unknown bytes, libinit.o(.ARM.Collect$$libinit$$00000000))

[Called By]

- >> __rt_entry_li

__rt_lib_init_alloca_1 (Thumb, 0 bytes, Stack size unknown bytes, libinit2.o(.ARM.Collect$$libinit$$00000030))

__rt_lib_init_argv_1 (Thumb, 0 bytes, Stack size unknown bytes, libinit2.o(.ARM.Collect$$libinit$$0000002E))

__rt_lib_init_atexit_1 (Thumb, 0 bytes, Stack size unknown bytes, libinit2.o(.ARM.Collect$$libinit$$0000001D))

__rt_lib_init_clock_1 (Thumb, 0 bytes, Stack size unknown bytes, libinit2.o(.ARM.Collect$$libinit$$00000023))

__rt_lib_init_cpp_1 (Thumb, 0 bytes, Stack size unknown bytes, libinit2.o(.ARM.Collect$$libinit$$00000034))

__rt_lib_init_exceptions_1 (Thumb, 0 bytes, Stack size unknown bytes, libinit2.o(.ARM.Collect$$libinit$$00000032))

__rt_lib_init_fp_1 (Thumb, 0 bytes, Stack size unknown bytes, libinit2.o(.ARM.Collect$$libinit$$00000002))

__rt_lib_init_fp_trap_1 (Thumb, 0 bytes, Stack size unknown bytes, libinit2.o(.ARM.Collect$$libinit$$00000021))

__rt_lib_init_getenv_1 (Thumb, 0 bytes, Stack size unknown bytes, libinit2.o(.ARM.Collect$$libinit$$00000025))

__rt_lib_init_heap_1 (Thumb, 0 bytes, Stack size unknown bytes, libinit2.o(.ARM.Collect$$libinit$$0000000C))

__rt_lib_init_lc_collate_1 (Thumb, 0 bytes, Stack size unknown bytes, libinit2.o(.ARM.Collect$$libinit$$00000013))

__rt_lib_init_lc_ctype_1 (Thumb, 0 bytes, Stack size unknown bytes, libinit2.o(.ARM.Collect$$libinit$$00000015))

__rt_lib_init_lc_monetary_1 (Thumb, 0 bytes, Stack size unknown bytes, libinit2.o(.ARM.Collect$$libinit$$00000017))

__rt_lib_init_lc_numeric_1 (Thumb, 0 bytes, Stack size unknown bytes, libinit2.o(.ARM.Collect$$libinit$$00000019))

__rt_lib_init_lc_time_1 (Thumb, 0 bytes, Stack size unknown bytes, libinit2.o(.ARM.Collect$$libinit$$0000001B))

__rt_lib_init_preinit_1 (Thumb, 0 bytes, Stack size unknown bytes, libinit2.o(.ARM.Collect$$libinit$$00000006))

__rt_lib_init_rand_1 (Thumb, 0 bytes, Stack size unknown bytes, libinit2.o(.ARM.Collect$$libinit$$00000010))

__rt_lib_init_relocate_pie_1 (Thumb, 0 bytes, Stack size unknown bytes, libinit2.o(.ARM.Collect$$libinit$$00000004))

__rt_lib_init_return (Thumb, 0 bytes, Stack size unknown bytes, libinit2.o(.ARM.Collect$$libinit$$00000035))

__rt_lib_init_signal_1 (Thumb, 0 bytes, Stack size unknown bytes, libinit2.o(.ARM.Collect$$libinit$$0000001F))

__rt_lib_init_stdio_1 (Thumb, 0 bytes, Stack size unknown bytes, libinit2.o(.ARM.Collect$$libinit$$00000027))

__rt_lib_init_user_alloc_1 (Thumb, 0 bytes, Stack size unknown bytes, libinit2.o(.ARM.Collect$$libinit$$0000000E))

__rt_lib_shutdown (Thumb, 0 bytes, Stack size unknown bytes, libshutdown.o(.ARM.Collect$$libshutdown$$00000000))

[Called By]

- >> __rt_exit_ls

__rt_lib_shutdown_cpp_1 (Thumb, 0 bytes, Stack size unknown bytes, libshutdown2.o(.ARM.Collect$$libshutdown$$00000002))

__rt_lib_shutdown_fp_trap_1 (Thumb, 0 bytes, Stack size unknown bytes, libshutdown2.o(.ARM.Collect$$libshutdown$$00000007))

__rt_lib_shutdown_heap_1 (Thumb, 0 bytes, Stack size unknown bytes, libshutdown2.o(.ARM.Collect$$libshutdown$$0000000F))

__rt_lib_shutdown_return (Thumb, 0 bytes, Stack size unknown bytes, libshutdown2.o(.ARM.Collect$$libshutdown$$00000010))

__rt_lib_shutdown_signal_1 (Thumb, 0 bytes, Stack size unknown bytes, libshutdown2.o(.ARM.Collect$$libshutdown$$0000000A))

__rt_lib_shutdown_stdio_1 (Thumb, 0 bytes, Stack size unknown bytes, libshutdown2.o(.ARM.Collect$$libshutdown$$00000004))

__rt_lib_shutdown_user_alloc_1 (Thumb, 0 bytes, Stack size unknown bytes, libshutdown2.o(.ARM.Collect$$libshutdown$$0000000C))

__rt_entry (Thumb, 0 bytes, Stack size unknown bytes, __rtentry.o(.ARM.Collect$$rtentry$$00000000))

[Called By]

- >> __main
- >> __scatterload_rt2

__rt_entry_presh_1 (Thumb, 0 bytes, Stack size unknown bytes, __rtentry2.o(.ARM.Collect$$rtentry$$00000002))

__rt_entry_sh (Thumb, 0 bytes, Stack size unknown bytes, __rtentry4.o(.ARM.Collect$$rtentry$$00000004))

[Stack]

- Max Depth = 8 + Unknown Stack Size
- Call Chain = __rt_entry_sh ⇒ __user_setup_stackheap

[Calls]

- >> __user_setup_stackheap

__rt_entry_li (Thumb, 0 bytes, Stack size unknown bytes, __rtentry2.o(.ARM.Collect$$rtentry$$0000000A))

[Calls]

- >> __rt_lib_init

__rt_entry_postsh_1 (Thumb, 0 bytes, Stack size unknown bytes, __rtentry2.o(.ARM.Collect$$rtentry$$00000009))

__rt_entry_main (Thumb, 0 bytes, Stack size unknown bytes, __rtentry2.o(.ARM.Collect$$rtentry$$0000000D))

[Stack]

- Max Depth = 272 + Unknown Stack Size
- Call Chain = __rt_entry_main ⇒ main ⇒ nrf24l01_receive ⇒ __2sprintf ⇒ _printf_char_common ⇒ __printf

[Calls]

- >> exit
- >> main

__rt_entry_postli_1 (Thumb, 0 bytes, Stack size unknown bytes, __rtentry2.o(.ARM.Collect$$rtentry$$0000000C))

__rt_exit (Thumb, 0 bytes, Stack size unknown bytes, rtexit.o(.ARM.Collect$$rtexit$$00000000))

[Called By]

- >> exit

__rt_exit_ls (Thumb, 0 bytes, Stack size unknown bytes, rtexit2.o(.ARM.Collect$$rtexit$$00000003))

[Calls]

- >> __rt_lib_shutdown

__rt_exit_prels_1 (Thumb, 0 bytes, Stack size unknown bytes, rtexit2.o(.ARM.Collect$$rtexit$$00000002))

__rt_exit_exit (Thumb, 0 bytes, Stack size unknown bytes, rtexit2.o(.ARM.Collect$$rtexit$$00000004))

[Calls]

- >> _sys_exit

Reset_Handler (Thumb, 8 bytes, Stack size 0 bytes, startup_stm32f030x6.o(.text))
[Address Reference Count : 1]

- startup_stm32f030x6.o(RESET)

ADC1_IRQHandler (Thumb, 0 bytes, Stack size 0 bytes, startup_stm32f030x6.o(.text))

[Calls]

- >> ADC1_IRQHandler

[Called By]

- >> ADC1_IRQHandler

[Address Reference Count : 1]

- startup_stm32f030x6.o(RESET)

DMA1_Channel1_IRQHandler (Thumb, 0 bytes, Stack size 0 bytes, startup_stm32f030x6.o(.text))
[Address Reference Count : 1]

- startup_stm32f030x6.o(RESET)

DMA1_Channel2_3_IRQHandler (Thumb, 0 bytes, Stack size 0 bytes, startup_stm32f030x6.o(.text))
[Address Reference Count : 1]

- startup_stm32f030x6.o(RESET)

DMA1_Channel4_5_IRQHandler (Thumb, 0 bytes, Stack size 0 bytes, startup_stm32f030x6.o(.text))
[Address Reference Count : 1]

- startup_stm32f030x6.o(RESET)

EXTI0_1_IRQHandler (Thumb, 0 bytes, Stack size 0 bytes, startup_stm32f030x6.o(.text))
[Address Reference Count : 1]

- startup_stm32f030x6.o(RESET)

EXTI4_15_IRQHandler (Thumb, 0 bytes, Stack size 0 bytes, startup_stm32f030x6.o(.text))
[Address Reference Count : 1]

- startup_stm32f030x6.o(RESET)

FLASH_IRQHandler (Thumb, 0 bytes, Stack size 0 bytes, startup_stm32f030x6.o(.text))
[Address Reference Count : 1]

- startup_stm32f030x6.o(RESET)

I2C1_IRQHandler (Thumb, 0 bytes, Stack size 0 bytes, startup_stm32f030x6.o(.text))
[Address Reference Count : 1]

- startup_stm32f030x6.o(RESET)

RCC_IRQHandler (Thumb, 0 bytes, Stack size 0 bytes, startup_stm32f030x6.o(.text))
[Address Reference Count : 1]

- startup_stm32f030x6.o(RESET)

RTC_IRQHandler (Thumb, 0 bytes, Stack size 0 bytes, startup_stm32f030x6.o(.text))
[Address Reference Count : 1]

- startup_stm32f030x6.o(RESET)

SPI1_IRQHandler (Thumb, 0 bytes, Stack size 0 bytes, startup_stm32f030x6.o(.text))
[Address Reference Count : 1]

- startup_stm32f030x6.o(RESET)

TIM14_IRQHandler (Thumb, 0 bytes, Stack size 0 bytes, startup_stm32f030x6.o(.text))
[Address Reference Count : 1]

- startup_stm32f030x6.o(RESET)

TIM16_IRQHandler (Thumb, 0 bytes, Stack size 0 bytes, startup_stm32f030x6.o(.text))
[Address Reference Count : 1]

- startup_stm32f030x6.o(RESET)

TIM17_IRQHandler (Thumb, 0 bytes, Stack size 0 bytes, startup_stm32f030x6.o(.text))
[Address Reference Count : 1]

- startup_stm32f030x6.o(RESET)

TIM1_BRK_UP_TRG_COM_IRQHandler (Thumb, 0 bytes, Stack size 0 bytes, startup_stm32f030x6.o(.text))
[Address Reference Count : 1]

- startup_stm32f030x6.o(RESET)

TIM3_IRQHandler (Thumb, 0 bytes, Stack size 0 bytes, startup_stm32f030x6.o(.text))
[Address Reference Count : 1]

- startup_stm32f030x6.o(RESET)

USART1_IRQHandler (Thumb, 0 bytes, Stack size 0 bytes, startup_stm32f030x6.o(.text))
[Address Reference Count : 1]

- startup_stm32f030x6.o(RESET)

WWDG_IRQHandler (Thumb, 0 bytes, Stack size 0 bytes, startup_stm32f030x6.o(.text))
[Address Reference Count : 1]

- startup_stm32f030x6.o(RESET)

__user_initial_stackheap (Thumb, 0 bytes, Stack size unknown bytes, startup_stm32f030x6.o(.text))

[Called By]

- >> __user_setup_stackheap

__2sprintf (Thumb, 36 bytes, Stack size 32 bytes, noretval__2sprintf.o(.text))

[Stack]

- Max Depth = 128 + Unknown Stack Size
- Call Chain = __2sprintf ⇒ _printf_char_common ⇒ __printf

[Calls]

- >> _sputc
- >> _printf_char_common

[Called By]

- >> nrf24l01_receive
- >> nrf_info_print

_printf_pre_padding (Thumb, 44 bytes, Stack size 16 bytes, _printf_pad.o(.text))

[Stack]

- Max Depth = 16
- Call Chain = _printf_pre_padding

[Called By]

- >> _printf_int_common

_printf_post_padding (Thumb, 34 bytes, Stack size 16 bytes, _printf_pad.o(.text))

[Stack]

- Max Depth = 16
- Call Chain = _printf_post_padding

[Called By]

- >> _printf_int_common

_printf_int_dec (Thumb, 90 bytes, Stack size 32 bytes, _printf_dec.o(.text))

[Stack]

- Max Depth = 88
- Call Chain = _printf_int_dec ⇒ _printf_int_common ⇒ _printf_post_padding

[Calls]

- >> __rt_udiv10
- >> _printf_int_common
- >> _printf_truncate_unsigned (Weak Reference)
- >> _printf_truncate_signed (Weak Reference)

[Called By]

- >> _printf_d

_printf_int_hex (Thumb, 84 bytes, Stack size 16 bytes, _printf_hex_int.o(.text))

[Stack]

- Max Depth = 72
- Call Chain = _printf_int_hex ⇒ _printf_int_common ⇒ _printf_post_padding

[Calls]

- >> _printf_int_common
- >> _printf_truncate_unsigned (Weak Reference)

[Called By]

- >> _printf_x

_printf_longlong_hex (Thumb, 0 bytes, Stack size 16 bytes, _printf_hex_int.o(.text), UNUSED)

__printf (Thumb, 306 bytes, Stack size 32 bytes, __printf_flags_wp.o(.text))

[Stack]

- Max Depth = 32 + Unknown Stack Size
- Call Chain = __printf

[Calls]

- >> _printf_percent
- >> _is_digit

[Called By]

- >> _printf_char_common

strlen (Thumb, 62 bytes, Stack size 12 bytes, strlen.o(.text))

[Stack]

- Max Depth = 12
- Call Chain = strlen

[Called By]

- >> usart_println
- >> usart_print

__use_two_region_memory (Thumb, 2 bytes, Stack size 0 bytes, heapauxi.o(.text), UNUSED)

__rt_heap_escrow$2region (Thumb, 2 bytes, Stack size 0 bytes, heapauxi.o(.text), UNUSED)

__rt_heap_expand$2region (Thumb, 2 bytes, Stack size 0 bytes, heapauxi.o(.text), UNUSED)

_printf_int_common (Thumb, 176 bytes, Stack size 40 bytes, _printf_intcommon.o(.text))

[Stack]

- Max Depth = 56
- Call Chain = _printf_int_common ⇒ _printf_post_padding

[Calls]

- >> _printf_post_padding
- >> _printf_pre_padding

[Called By]

- >> _printf_int_hex
- >> _printf_int_dec

_printf_char_common (Thumb, 32 bytes, Stack size 64 bytes, _printf_char_common.o(.text))

[Stack]

- Max Depth = 96 + Unknown Stack Size
- Call Chain = _printf_char_common ⇒ __printf

[Calls]

- >> __printf

[Called By]

- >> __2sprintf

_sputc (Thumb, 10 bytes, Stack size 0 bytes, _sputc.o(.text))

[Called By]

- >> __2sprintf

[Address Reference Count : 1]

- noretval__2sprintf.o(.text)

__rt_udiv10 (Thumb, 40 bytes, Stack size 0 bytes, rtudiv10.o(.text))

[Called By]

- >> _printf_int_dec

__user_setup_stackheap (Thumb, 62 bytes, Stack size 8 bytes, sys_stackheap_outer.o(.text))

[Stack]

- Max Depth = 8 + Unknown Stack Size
- Call Chain = __user_setup_stackheap

[Calls]

- >> __user_perproc_libspace
- >> __user_initial_stackheap

[Called By]

- >> __rt_entry_sh

exit (Thumb, 16 bytes, Stack size 8 bytes, exit.o(.text))

[Stack]

- Max Depth = 8 + Unknown Stack Size
- Call Chain = exit

[Calls]

- >> __rt_exit
- >> _call_atexit_fns (Weak Reference)

[Called By]

- >> __rt_entry_main

__user_libspace (Thumb, 8 bytes, Stack size 0 bytes, libspace.o(.text), UNUSED)

__user_perproc_libspace (Thumb, 0 bytes, Stack size 0 bytes, libspace.o(.text))

[Called By]

- >> __user_setup_stackheap

__user_perthread_libspace (Thumb, 0 bytes, Stack size 0 bytes, libspace.o(.text), UNUSED)

_sys_exit (Thumb, 8 bytes, Stack size 0 bytes, sys_exit.o(.text))

[Called By]

- >> __rt_exit_exit

__I$use$semihosting (Thumb, 0 bytes, Stack size 0 bytes, use_no_semi.o(.text), UNUSED)

__use_no_semihosting_swi (Thumb, 2 bytes, Stack size 0 bytes, use_no_semi.o(.text), UNUSED)

__semihosting_library_function (Thumb, 0 bytes, Stack size unknown bytes, indicate_semi.o(.text), UNUSED)

EXTI2_3_IRQHandler (Thumb, 20 bytes, Stack size 8 bytes, stm32f0xx_it.o(.text.EXTI2_3_IRQHandler))

[Stack]

- Max Depth = 64
- Call Chain = EXTI2_3_IRQHandler ⇒ irq_callback ⇒ nrf24_rx_mode

[Calls]

- >> irq_callback

[Address Reference Count : 1]

- startup_stm32f030x6.o(RESET)

HardFault_Handler (Thumb, 2 bytes, Stack size 0 bytes, stm32f0xx_it.o(.text.HardFault_Handler))

[Calls]

- >> HardFault_Handler

[Called By]

- >> HardFault_Handler

[Address Reference Count : 1]

- startup_stm32f030x6.o(RESET)

LL_EXTI_Init (Thumb, 164 bytes, Stack size 8 bytes, stm32f0xx_ll_exti.o(.text.LL_EXTI_Init))

[Stack]

- Max Depth = 8
- Call Chain = LL_EXTI_Init

[Called By]

- >> main

LL_GPIO_Init (Thumb, 174 bytes, Stack size 28 bytes, stm32f0xx_ll_gpio.o(.text.LL_GPIO_Init))

[Stack]

- Max Depth = 28
- Call Chain = LL_GPIO_Init

[Called By]

- >> main

LL_Init1msTick (Thumb, 28 bytes, Stack size 8 bytes, stm32f0xx_ll_utils.o(.text.LL_Init1msTick))

[Stack]

- Max Depth = 8
- Call Chain = LL_Init1msTick

[Calls]

- >> __aeabi_uidiv

[Called By]

- >> SystemClock_Config

LL_RCC_GetUSARTClockFreq (Thumb, 172 bytes, Stack size 8 bytes, stm32f0xx_ll_rcc.o(.text.LL_RCC_GetUSARTClockFreq))

[Stack]

- Max Depth = 8
- Call Chain = LL_RCC_GetUSARTClockFreq

[Calls]

- >> __aeabi_uidiv

[Called By]

- >> LL_USART_Init

LL_SPI_Init (Thumb, 100 bytes, Stack size 16 bytes, stm32f0xx_ll_spi.o(.text.LL_SPI_Init))

[Stack]

- Max Depth = 16
- Call Chain = LL_SPI_Init

[Called By]

- >> main

LL_SetSystemCoreClock (Thumb, 8 bytes, Stack size 0 bytes, stm32f0xx_ll_utils.o(.text.LL_SetSystemCoreClock))

[Called By]

- >> SystemClock_Config

LL_TIM_Init (Thumb, 124 bytes, Stack size 8 bytes, stm32f0xx_ll_tim.o(.text.LL_TIM_Init))

[Stack]

- Max Depth = 8
- Call Chain = LL_TIM_Init

[Called By]

- >> main

LL_USART_Init (Thumb, 148 bytes, Stack size 24 bytes, stm32f0xx_ll_usart.o(.text.LL_USART_Init))

[Stack]

- Max Depth = 32
- Call Chain = LL_USART_Init ⇒ LL_RCC_GetUSARTClockFreq

[Calls]

- >> __aeabi_uidiv
- >> LL_RCC_GetUSARTClockFreq

[Called By]

- >> main

LL_mDelay (Thumb, 64 bytes, Stack size 4 bytes, stm32f0xx_ll_utils.o(.text.LL_mDelay))

[Stack]

- Max Depth = 4
- Call Chain = LL_mDelay

[Called By]

- >> main

NMI_Handler (Thumb, 2 bytes, Stack size 0 bytes, stm32f0xx_it.o(.text.NMI_Handler))

[Calls]

- >> NMI_Handler

[Called By]

- >> NMI_Handler

[Address Reference Count : 1]

- startup_stm32f030x6.o(RESET)

PendSV_Handler (Thumb, 2 bytes, Stack size 0 bytes, stm32f0xx_it.o(.text.PendSV_Handler))
[Address Reference Count : 1]

- startup_stm32f030x6.o(RESET)

SVC_Handler (Thumb, 2 bytes, Stack size 0 bytes, stm32f0xx_it.o(.text.SVC_Handler))
[Address Reference Count : 1]

- startup_stm32f030x6.o(RESET)

SysTick_Handler (Thumb, 2 bytes, Stack size 0 bytes, stm32f0xx_it.o(.text.SysTick_Handler))
[Address Reference Count : 1]

- startup_stm32f030x6.o(RESET)

SystemClock_Config (Thumb, 256 bytes, Stack size 16 bytes, main.o(.text.SystemClock_Config))

[Stack]

- Max Depth = 24
- Call Chain = SystemClock_Config ⇒ LL_Init1msTick

[Calls]

- >> LL_SetSystemCoreClock
- >> LL_Init1msTick

[Called By]

- >> main

SystemInit (Thumb, 2 bytes, Stack size 0 bytes, system_stm32f0xx.o(.text.SystemInit))
[Address Reference Count : 1]

- startup_stm32f030x6.o(.text)

TIM1_CC_IRQHandler (Thumb, 8 bytes, Stack size 8 bytes, stm32f0xx_it.o(.text.TIM1_CC_IRQHandler))

[Stack]

- Max Depth = 8
- Call Chain = TIM1_CC_IRQHandler

[Calls]

- >> TIM1_Callback

[Address Reference Count : 1]

- startup_stm32f030x6.o(RESET)

TIM1_Callback (Thumb, 16 bytes, Stack size 0 bytes, main.o(.text.TIM1_Callback))

[Called By]

- >> TIM1_CC_IRQHandler

irq_callback (Thumb, 528 bytes, Stack size 32 bytes, kombo_nrf24.o(.text.irq_callback))

[Stack]

- Max Depth = 56
- Call Chain = irq_callback ⇒ nrf24_rx_mode

[Calls]

- >> __aeabi_uidiv
- >> nrf24_rx_mode
- >> spi_send_byte
- >> spi_change_byte

[Called By]

- >> EXTI2_3_IRQHandler

main (Thumb, 840 bytes, Stack size 120 bytes, main.o(.text.main))

[Stack]

- Max Depth = 272 + Unknown Stack Size
- Call Chain = main ⇒ nrf24l01_receive ⇒ __2sprintf ⇒ _printf_char_common ⇒ __printf

[Calls]

- >> nrf24_send
- >> nrf24_init
- >> usart_println
- >> usart_init
- >> LL_TIM_Init
- >> LL_USART_Init
- >> LL_SPI_Init
- >> LL_GPIO_Init
- >> LL_EXTI_Init
- >> SystemClock_Config
- >> nrf24l01_receive
- >> LL_mDelay
- >> nrf_info_print

[Called By]

- >> __rt_entry_main

nrf24_init (Thumb, 588 bytes, Stack size 32 bytes, kombo_nrf24.o(.text.nrf24_init))

[Stack]

- Max Depth = 56
- Call Chain = nrf24_init ⇒ nrf24_rx_mode

[Calls]

- >> __aeabi_uidiv
- >> nrf24_rx_mode
- >> spi_send_byte

[Called By]

- >> main

nrf24_read_buf (Thumb, 52 bytes, Stack size 24 bytes, kombo_nrf24.o(.text.nrf24_read_buf))

[Stack]

- Max Depth = 24
- Call Chain = nrf24_read_buf

[Calls]

- >> spi_send_byte
- >> spi_change_byte

[Called By]

- >> nrf_info_print

nrf24_read_reg (Thumb, 28 bytes, Stack size 16 bytes, kombo_nrf24.o(.text.nrf24_read_reg))

[Stack]

- Max Depth = 16
- Call Chain = nrf24_read_reg

[Calls]

- >> spi_change_byte

[Called By]

- >> nrf_info_print

nrf24_rx_mode (Thumb, 420 bytes, Stack size 24 bytes, kombo_nrf24.o(.text.nrf24_rx_mode))

[Stack]

- Max Depth = 24
- Call Chain = nrf24_rx_mode

[Calls]

- >> __aeabi_uidiv
- >> spi_send_byte
- >> spi_change_byte

[Called By]

- >> irq_callback
- >> nrf24_init

nrf24_send (Thumb, 456 bytes, Stack size 32 bytes, kombo_nrf24.o(.text.nrf24_send))

[Stack]

- Max Depth = 56
- Call Chain = nrf24_send ⇒ nrf24_tx_mode

[Calls]

- >> __aeabi_uidiv
- >> nrf24_tx_mode
- >> spi_send_byte
- >> spi_change_byte

[Called By]

- >> main

nrf24_tx_mode (Thumb, 340 bytes, Stack size 24 bytes, kombo_nrf24.o(.text.nrf24_tx_mode))

[Stack]

- Max Depth = 24
- Call Chain = nrf24_tx_mode

[Calls]

- >> __aeabi_uidiv
- >> spi_send_byte

[Called By]

- >> nrf24_send

nrf24l01_receive (Thumb, 720 bytes, Stack size 24 bytes, main.o(.text.nrf24l01_receive))

[Stack]

- Max Depth = 152 + Unknown Stack Size
- Call Chain = nrf24l01_receive ⇒ __2sprintf ⇒ _printf_char_common ⇒ __printf

[Calls]

- >> __2sprintf
- >> usart_print

[Called By]

- >> main
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

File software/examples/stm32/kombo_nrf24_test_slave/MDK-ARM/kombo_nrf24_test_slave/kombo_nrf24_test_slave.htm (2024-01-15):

# Static Call Graph for image kombo_nrf24_test_slave\kombo_nrf24_test_slave.axf

#<CALLGRAPH># ARM Linker, 6190004: Last Updated: Thu Dec 21 12:56:47 2023

### Maximum Stack Usage = 272 bytes + Unknown(Functions without stacksize, Cycles, Untraceable Function Pointers)

### Call chain for Maximum Stack Depth:

__rt_entry_main ⇒ main ⇒ nrf_info_print ⇒ __2sprintf ⇒ _printf_char_common ⇒ __printf

### Functions with no stack information

- __user_initial_stackheap

### Mutually Recursive functions

- ADC1_IRQHandler ⇒ ADC1_IRQHandler
- HardFault_Handler ⇒ HardFault_Handler
- NMI_Handler ⇒ NMI_Handler

### Function Pointers

- ADC1_IRQHandler from startup_stm32f030x6.o(.text) referenced from startup_stm32f030x6.o(RESET)
- DMA1_Channel1_IRQHandler from startup_stm32f030x6.o(.text) referenced from startup_stm32f030x6.o(RESET)
- DMA1_Channel2_3_IRQHandler from startup_stm32f030x6.o(.text) referenced from startup_stm32f030x6.o(RESET)
- DMA1_Channel4_5_IRQHandler from startup_stm32f030x6.o(.text) referenced from startup_stm32f030x6.o(RESET)
- EXTI0_1_IRQHandler from startup_stm32f030x6.o(.text) referenced from startup_stm32f030x6.o(RESET)
- EXTI2_3_IRQHandler from stm32f0xx_it.o(.text.EXTI2_3_IRQHandler) referenced from startup_stm32f030x6.o(RESET)
- EXTI4_15_IRQHandler from startup_stm32f030x6.o(.text) referenced from startup_stm32f030x6.o(RESET)
- FLASH_IRQHandler from startup_stm32f030x6.o(.text) referenced from startup_stm32f030x6.o(RESET)
- HardFault_Handler from stm32f0xx_it.o(.text.HardFault_Handler) referenced from startup_stm32f030x6.o(RESET)
- I2C1_IRQHandler from startup_stm32f030x6.o(.text) referenced from startup_stm32f030x6.o(RESET)
- NMI_Handler from stm32f0xx_it.o(.text.NMI_Handler) referenced from startup_stm32f030x6.o(RESET)
- PendSV_Handler from stm32f0xx_it.o(.text.PendSV_Handler) referenced from startup_stm32f030x6.o(RESET)
- RCC_IRQHandler from startup_stm32f030x6.o(.text) referenced from startup_stm32f030x6.o(RESET)
- RTC_IRQHandler from startup_stm32f030x6.o(.text) referenced from startup_stm32f030x6.o(RESET)
- Reset_Handler from startup_stm32f030x6.o(.text) referenced from startup_stm32f030x6.o(RESET)
- SPI1_IRQHandler from startup_stm32f030x6.o(.text) referenced from startup_stm32f030x6.o(RESET)
- SVC_Handler from stm32f0xx_it.o(.text.SVC_Handler) referenced from startup_stm32f030x6.o(RESET)
- SysTick_Handler from stm32f0xx_it.o(.text.SysTick_Handler) referenced from startup_stm32f030x6.o(RESET)
- SystemInit from system_stm32f0xx.o(.text.SystemInit) referenced from startup_stm32f030x6.o(.text)
- TIM14_IRQHandler from startup_stm32f030x6.o(.text) referenced from startup_stm32f030x6.o(RESET)
- TIM16_IRQHandler from startup_stm32f030x6.o(.text) referenced from startup_stm32f030x6.o(RESET)
- TIM17_IRQHandler from startup_stm32f030x6.o(.text) referenced from startup_stm32f030x6.o(RESET)
- TIM1_BRK_UP_TRG_COM_IRQHandler from startup_stm32f030x6.o(.text) referenced from startup_stm32f030x6.o(RESET)
- TIM1_CC_IRQHandler from stm32f0xx_it.o(.text.TIM1_CC_IRQHandler) referenced from startup_stm32f030x6.o(RESET)
- TIM3_IRQHandler from startup_stm32f030x6.o(.text) referenced from startup_stm32f030x6.o(RESET)
- USART1_IRQHandler from startup_stm32f030x6.o(.text) referenced from startup_stm32f030x6.o(RESET)
- WWDG_IRQHandler from startup_stm32f030x6.o(.text) referenced from startup_stm32f030x6.o(RESET)
- __main from __main.o(!!!main) referenced from startup_stm32f030x6.o(.text)
- _printf_input_char from _printf_char_common.o(.text) referenced from _printf_char_common.o(.text)
- _sputc from _sputc.o(.text) referenced from noretval__2sprintf.o(.text)

### Global Symbols

__main (Thumb, 8 bytes, Stack size 0 bytes, __main.o(!!!main))

[Calls]

- >> __rt_entry
- >> __scatterload

[Address Reference Count : 1]

- startup_stm32f030x6.o(.text)

__scatterload (Thumb, 0 bytes, Stack size unknown bytes, __scatter.o(!!!scatter))

[Called By]

- >> __main

__scatterload_rt2 (Thumb, 52 bytes, Stack size unknown bytes, __scatter.o(!!!scatter), UNUSED)

[Calls]

- >> __rt_entry

__scatterload_rt2_thumb_only (Thumb, 0 bytes, Stack size unknown bytes, __scatter.o(!!!scatter), UNUSED)

__scatterload_null (Thumb, 0 bytes, Stack size unknown bytes, __scatter.o(!!!scatter), UNUSED)

__scatterload_copy (Thumb, 26 bytes, Stack size unknown bytes, __scatter_copy.o(!!handler_copy), UNUSED)

[Calls]

- >> __scatterload_copy

[Called By]

- >> __scatterload_copy

__scatterload_zeroinit (Thumb, 28 bytes, Stack size unknown bytes, __scatter_zi.o(!!handler_zi), UNUSED)

_printf_percent (Thumb, 0 bytes, Stack size unknown bytes, _printf_percent.o(.ARM.Collect$$_printf_percent$$00000000))

[Called By]

- >> __printf

_printf_d (Thumb, 0 bytes, Stack size unknown bytes, _printf_d.o(.ARM.Collect$$_printf_percent$$00000009))

[Stack]

- Max Depth = 88 + Unknown Stack Size
- Call Chain = _printf_d ⇒ _printf_int_dec ⇒ _printf_int_common ⇒ _printf_post_padding

[Calls]

- >> _printf_x
- >> _printf_int_dec

_printf_x (Thumb, 0 bytes, Stack size unknown bytes, _printf_x.o(.ARM.Collect$$_printf_percent$$0000000C))

[Stack]

- Max Depth = 72 + Unknown Stack Size
- Call Chain = _printf_x ⇒ _printf_int_hex ⇒ _printf_int_common ⇒ _printf_post_padding

[Calls]

- >> _printf_percent_end
- >> _printf_int_hex

[Called By]

- >> _printf_d

_printf_percent_end (Thumb, 0 bytes, Stack size unknown bytes, _printf_percent_end.o(.ARM.Collect$$_printf_percent$$00000017))

[Called By]

- >> _printf_x

__rt_lib_init (Thumb, 0 bytes, Stack size unknown bytes, libinit.o(.ARM.Collect$$libinit$$00000000))

[Called By]

- >> __rt_entry_li

__rt_lib_init_alloca_1 (Thumb, 0 bytes, Stack size unknown bytes, libinit2.o(.ARM.Collect$$libinit$$00000030))

__rt_lib_init_argv_1 (Thumb, 0 bytes, Stack size unknown bytes, libinit2.o(.ARM.Collect$$libinit$$0000002E))

__rt_lib_init_atexit_1 (Thumb, 0 bytes, Stack size unknown bytes, libinit2.o(.ARM.Collect$$libinit$$0000001D))

__rt_lib_init_clock_1 (Thumb, 0 bytes, Stack size unknown bytes, libinit2.o(.ARM.Collect$$libinit$$00000023))

__rt_lib_init_cpp_1 (Thumb, 0 bytes, Stack size unknown bytes, libinit2.o(.ARM.Collect$$libinit$$00000034))

__rt_lib_init_exceptions_1 (Thumb, 0 bytes, Stack size unknown bytes, libinit2.o(.ARM.Collect$$libinit$$00000032))

__rt_lib_init_fp_1 (Thumb, 0 bytes, Stack size unknown bytes, libinit2.o(.ARM.Collect$$libinit$$00000002))

__rt_lib_init_fp_trap_1 (Thumb, 0 bytes, Stack size unknown bytes, libinit2.o(.ARM.Collect$$libinit$$00000021))

__rt_lib_init_getenv_1 (Thumb, 0 bytes, Stack size unknown bytes, libinit2.o(.ARM.Collect$$libinit$$00000025))

__rt_lib_init_heap_1 (Thumb, 0 bytes, Stack size unknown bytes, libinit2.o(.ARM.Collect$$libinit$$0000000C))

__rt_lib_init_lc_collate_1 (Thumb, 0 bytes, Stack size unknown bytes, libinit2.o(.ARM.Collect$$libinit$$00000013))

__rt_lib_init_lc_ctype_1 (Thumb, 0 bytes, Stack size unknown bytes, libinit2.o(.ARM.Collect$$libinit$$00000015))

__rt_lib_init_lc_monetary_1 (Thumb, 0 bytes, Stack size unknown bytes, libinit2.o(.ARM.Collect$$libinit$$00000017))

__rt_lib_init_lc_numeric_1 (Thumb, 0 bytes, Stack size unknown bytes, libinit2.o(.ARM.Collect$$libinit$$00000019))

__rt_lib_init_lc_time_1 (Thumb, 0 bytes, Stack size unknown bytes, libinit2.o(.ARM.Collect$$libinit$$0000001B))

__rt_lib_init_preinit_1 (Thumb, 0 bytes, Stack size unknown bytes, libinit2.o(.ARM.Collect$$libinit$$00000006))

__rt_lib_init_rand_1 (Thumb, 0 bytes, Stack size unknown bytes, libinit2.o(.ARM.Collect$$libinit$$00000010))

__rt_lib_init_relocate_pie_1 (Thumb, 0 bytes, Stack size unknown bytes, libinit2.o(.ARM.Collect$$libinit$$00000004))

__rt_lib_init_return (Thumb, 0 bytes, Stack size unknown bytes, libinit2.o(.ARM.Collect$$libinit$$00000035))

__rt_lib_init_signal_1 (Thumb, 0 bytes, Stack size unknown bytes, libinit2.o(.ARM.Collect$$libinit$$0000001F))

__rt_lib_init_stdio_1 (Thumb, 0 bytes, Stack size unknown bytes, libinit2.o(.ARM.Collect$$libinit$$00000027))

__rt_lib_init_user_alloc_1 (Thumb, 0 bytes, Stack size unknown bytes, libinit2.o(.ARM.Collect$$libinit$$0000000E))

__rt_lib_shutdown (Thumb, 0 bytes, Stack size unknown bytes, libshutdown.o(.ARM.Collect$$libshutdown$$00000000))

[Called By]

- >> __rt_exit_ls

__rt_lib_shutdown_cpp_1 (Thumb, 0 bytes, Stack size unknown bytes, libshutdown2.o(.ARM.Collect$$libshutdown$$00000002))

__rt_lib_shutdown_fp_trap_1 (Thumb, 0 bytes, Stack size unknown bytes, libshutdown2.o(.ARM.Collect$$libshutdown$$00000007))

__rt_lib_shutdown_heap_1 (Thumb, 0 bytes, Stack size unknown bytes, libshutdown2.o(.ARM.Collect$$libshutdown$$0000000F))

__rt_lib_shutdown_return (Thumb, 0 bytes, Stack size unknown bytes, libshutdown2.o(.ARM.Collect$$libshutdown$$00000010))

__rt_lib_shutdown_signal_1 (Thumb, 0 bytes, Stack size unknown bytes, libshutdown2.o(.ARM.Collect$$libshutdown$$0000000A))

__rt_lib_shutdown_stdio_1 (Thumb, 0 bytes, Stack size unknown bytes, libshutdown2.o(.ARM.Collect$$libshutdown$$00000004))

__rt_lib_shutdown_user_alloc_1 (Thumb, 0 bytes, Stack size unknown bytes, libshutdown2.o(.ARM.Collect$$libshutdown$$0000000C))

__rt_entry (Thumb, 0 bytes, Stack size unknown bytes, __rtentry.o(.ARM.Collect$$rtentry$$00000000))

[Called By]

- >> __main
- >> __scatterload_rt2

__rt_entry_presh_1 (Thumb, 0 bytes, Stack size unknown bytes, __rtentry2.o(.ARM.Collect$$rtentry$$00000002))

__rt_entry_sh (Thumb, 0 bytes, Stack size unknown bytes, __rtentry4.o(.ARM.Collect$$rtentry$$00000004))

[Stack]

- Max Depth = 8 + Unknown Stack Size
- Call Chain = __rt_entry_sh ⇒ __user_setup_stackheap

[Calls]

- >> __user_setup_stackheap

__rt_entry_li (Thumb, 0 bytes, Stack size unknown bytes, __rtentry2.o(.ARM.Collect$$rtentry$$0000000A))

[Calls]

- >> __rt_lib_init

__rt_entry_postsh_1 (Thumb, 0 bytes, Stack size unknown bytes, __rtentry2.o(.ARM.Collect$$rtentry$$00000009))

__rt_entry_main (Thumb, 0 bytes, Stack size unknown bytes, __rtentry2.o(.ARM.Collect$$rtentry$$0000000D))

[Stack]

- Max Depth = 272 + Unknown Stack Size
- Call Chain = __rt_entry_main ⇒ main ⇒ nrf_info_print ⇒ __2sprintf ⇒ _printf_char_common ⇒ __printf

[Calls]

- >> exit
- >> main

__rt_entry_postli_1 (Thumb, 0 bytes, Stack size unknown bytes, __rtentry2.o(.ARM.Collect$$rtentry$$0000000C))

__rt_exit (Thumb, 0 bytes, Stack size unknown bytes, rtexit.o(.ARM.Collect$$rtexit$$00000000))

[Called By]

- >> exit

__rt_exit_ls (Thumb, 0 bytes, Stack size unknown bytes, rtexit2.o(.ARM.Collect$$rtexit$$00000003))

[Calls]

- >> __rt_lib_shutdown

__rt_exit_prels_1 (Thumb, 0 bytes, Stack size unknown bytes, rtexit2.o(.ARM.Collect$$rtexit$$00000002))

__rt_exit_exit (Thumb, 0 bytes, Stack size unknown bytes, rtexit2.o(.ARM.Collect$$rtexit$$00000004))

[Calls]

- >> _sys_exit

Reset_Handler (Thumb, 8 bytes, Stack size 0 bytes, startup_stm32f030x6.o(.text))
[Address Reference Count : 1]

- startup_stm32f030x6.o(RESET)

ADC1_IRQHandler (Thumb, 0 bytes, Stack size 0 bytes, startup_stm32f030x6.o(.text))

[Calls]

- >> ADC1_IRQHandler

[Called By]

- >> ADC1_IRQHandler

[Address Reference Count : 1]

- startup_stm32f030x6.o(RESET)

DMA1_Channel1_IRQHandler (Thumb, 0 bytes, Stack size 0 bytes, startup_stm32f030x6.o(.text))
[Address Reference Count : 1]

- startup_stm32f030x6.o(RESET)

DMA1_Channel2_3_IRQHandler (Thumb, 0 bytes, Stack size 0 bytes, startup_stm32f030x6.o(.text))
[Address Reference Count : 1]

- startup_stm32f030x6.o(RESET)

DMA1_Channel4_5_IRQHandler (Thumb, 0 bytes, Stack size 0 bytes, startup_stm32f030x6.o(.text))
[Address Reference Count : 1]

- startup_stm32f030x6.o(RESET)

EXTI0_1_IRQHandler (Thumb, 0 bytes, Stack size 0 bytes, startup_stm32f030x6.o(.text))
[Address Reference Count : 1]

- startup_stm32f030x6.o(RESET)

EXTI4_15_IRQHandler (Thumb, 0 bytes, Stack size 0 bytes, startup_stm32f030x6.o(.text))
[Address Reference Count : 1]

- startup_stm32f030x6.o(RESET)

FLASH_IRQHandler (Thumb, 0 bytes, Stack size 0 bytes, startup_stm32f030x6.o(.text))
[Address Reference Count : 1]

- startup_stm32f030x6.o(RESET)

I2C1_IRQHandler (Thumb, 0 bytes, Stack size 0 bytes, startup_stm32f030x6.o(.text))
[Address Reference Count : 1]

- startup_stm32f030x6.o(RESET)

RCC_IRQHandler (Thumb, 0 bytes, Stack size 0 bytes, startup_stm32f030x6.o(.text))
[Address Reference Count : 1]

- startup_stm32f030x6.o(RESET)

RTC_IRQHandler (Thumb, 0 bytes, Stack size 0 bytes, startup_stm32f030x6.o(.text))
[Address Reference Count : 1]

- startup_stm32f030x6.o(RESET)

SPI1_IRQHandler (Thumb, 0 bytes, Stack size 0 bytes, startup_stm32f030x6.o(.text))
[Address Reference Count : 1]

- startup_stm32f030x6.o(RESET)

TIM14_IRQHandler (Thumb, 0 bytes, Stack size 0 bytes, startup_stm32f030x6.o(.text))
[Address Reference Count : 1]

- startup_stm32f030x6.o(RESET)

TIM16_IRQHandler (Thumb, 0 bytes, Stack size 0 bytes, startup_stm32f030x6.o(.text))
[Address Reference Count : 1]

- startup_stm32f030x6.o(RESET)

TIM17_IRQHandler (Thumb, 0 bytes, Stack size 0 bytes, startup_stm32f030x6.o(.text))
[Address Reference Count : 1]

- startup_stm32f030x6.o(RESET)

TIM1_BRK_UP_TRG_COM_IRQHandler (Thumb, 0 bytes, Stack size 0 bytes, startup_stm32f030x6.o(.text))
[Address Reference Count : 1]

- startup_stm32f030x6.o(RESET)

TIM3_IRQHandler (Thumb, 0 bytes, Stack size 0 bytes, startup_stm32f030x6.o(.text))
[Address Reference Count : 1]

- startup_stm32f030x6.o(RESET)

USART1_IRQHandler (Thumb, 0 bytes, Stack size 0 bytes, startup_stm32f030x6.o(.text))
[Address Reference Count : 1]

- startup_stm32f030x6.o(RESET)

WWDG_IRQHandler (Thumb, 0 bytes, Stack size 0 bytes, startup_stm32f030x6.o(.text))
[Address Reference Count : 1]

- startup_stm32f030x6.o(RESET)

__user_initial_stackheap (Thumb, 0 bytes, Stack size unknown bytes, startup_stm32f030x6.o(.text))

[Called By]

- >> __user_setup_stackheap

__2sprintf (Thumb, 36 bytes, Stack size 32 bytes, noretval__2sprintf.o(.text))

[Stack]

- Max Depth = 128 + Unknown Stack Size
- Call Chain = __2sprintf ⇒ _printf_char_common ⇒ __printf

[Calls]

- >> _sputc
- >> _printf_char_common

[Called By]

- >> main
- >> nrf_info_print

_printf_pre_padding (Thumb, 44 bytes, Stack size 16 bytes, _printf_pad.o(.text))

[Stack]

- Max Depth = 16
- Call Chain = _printf_pre_padding

[Called By]

- >> _printf_int_common

_printf_post_padding (Thumb, 34 bytes, Stack size 16 bytes, _printf_pad.o(.text))

[Stack]

- Max Depth = 16
- Call Chain = _printf_post_padding

[Called By]

- >> _printf_int_common

_printf_int_dec (Thumb, 90 bytes, Stack size 32 bytes, _printf_dec.o(.text))

[Stack]

- Max Depth = 88
- Call Chain = _printf_int_dec ⇒ _printf_int_common ⇒ _printf_post_padding

[Calls]

- >> __rt_udiv10
- >> _printf_int_common
- >> _printf_truncate_unsigned (Weak Reference)
- >> _printf_truncate_signed (Weak Reference)

[Called By]

- >> _printf_d

_printf_int_hex (Thumb, 84 bytes, Stack size 16 bytes, _printf_hex_int.o(.text))

[Stack]

- Max Depth = 72
- Call Chain = _printf_int_hex ⇒ _printf_int_common ⇒ _printf_post_padding

[Calls]

- >> _printf_int_common
- >> _printf_truncate_unsigned (Weak Reference)

[Called By]

- >> _printf_x

_printf_longlong_hex (Thumb, 0 bytes, Stack size 16 bytes, _printf_hex_int.o(.text), UNUSED)

__printf (Thumb, 306 bytes, Stack size 32 bytes, __printf_flags_wp.o(.text))

[Stack]

- Max Depth = 32 + Unknown Stack Size
- Call Chain = __printf

[Calls]

- >> _printf_percent
- >> _is_digit

[Called By]

- >> _printf_char_common

strlen (Thumb, 62 bytes, Stack size 12 bytes, strlen.o(.text))

[Stack]

- Max Depth = 12
- Call Chain = strlen

[Called By]

- >> usart_println
- >> usart_print

__use_two_region_memory (Thumb, 2 bytes, Stack size 0 bytes, heapauxi.o(.text), UNUSED)

__rt_heap_escrow$2region (Thumb, 2 bytes, Stack size 0 bytes, heapauxi.o(.text), UNUSED)

__rt_heap_expand$2region (Thumb, 2 bytes, Stack size 0 bytes, heapauxi.o(.text), UNUSED)
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

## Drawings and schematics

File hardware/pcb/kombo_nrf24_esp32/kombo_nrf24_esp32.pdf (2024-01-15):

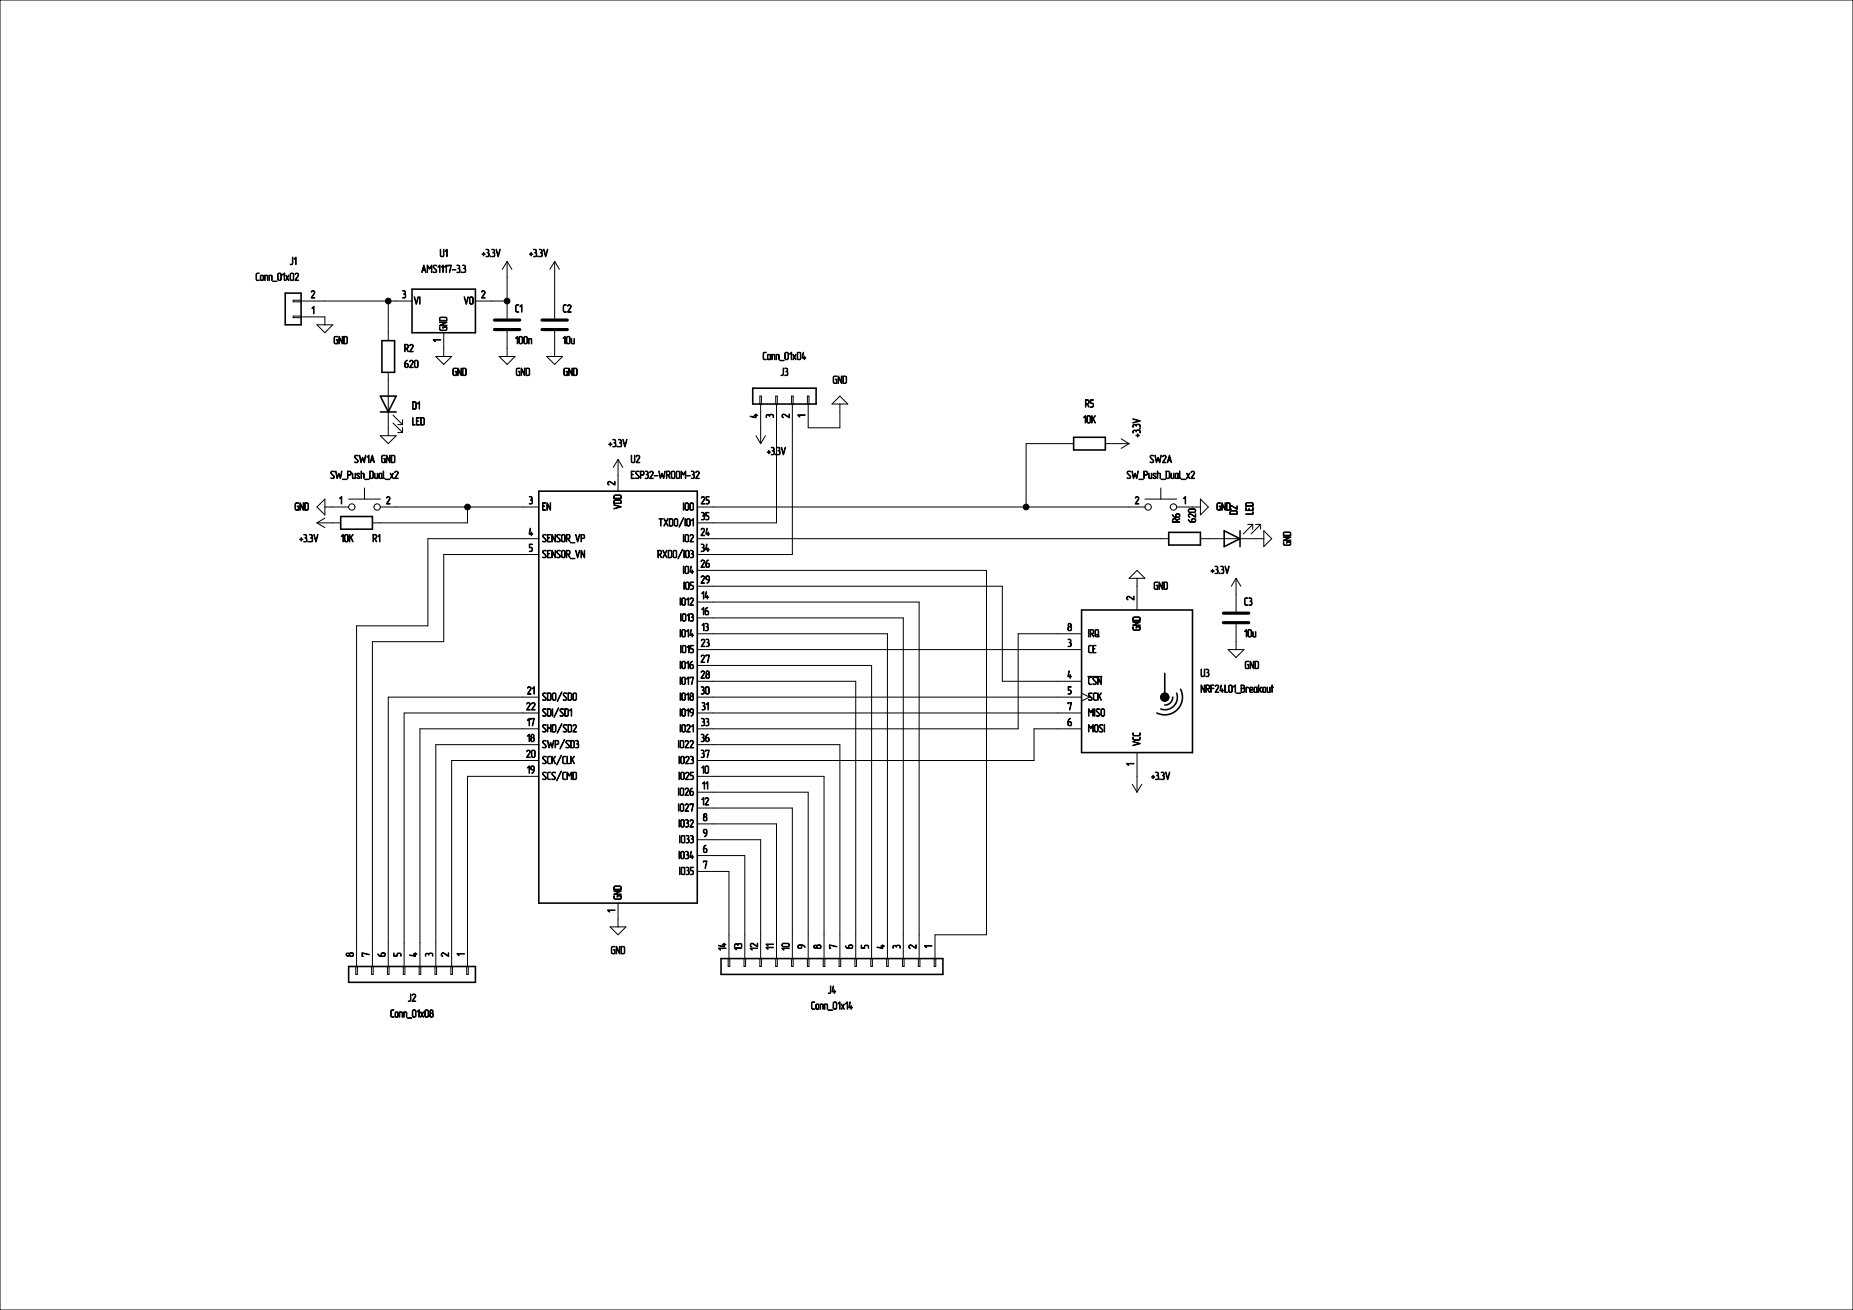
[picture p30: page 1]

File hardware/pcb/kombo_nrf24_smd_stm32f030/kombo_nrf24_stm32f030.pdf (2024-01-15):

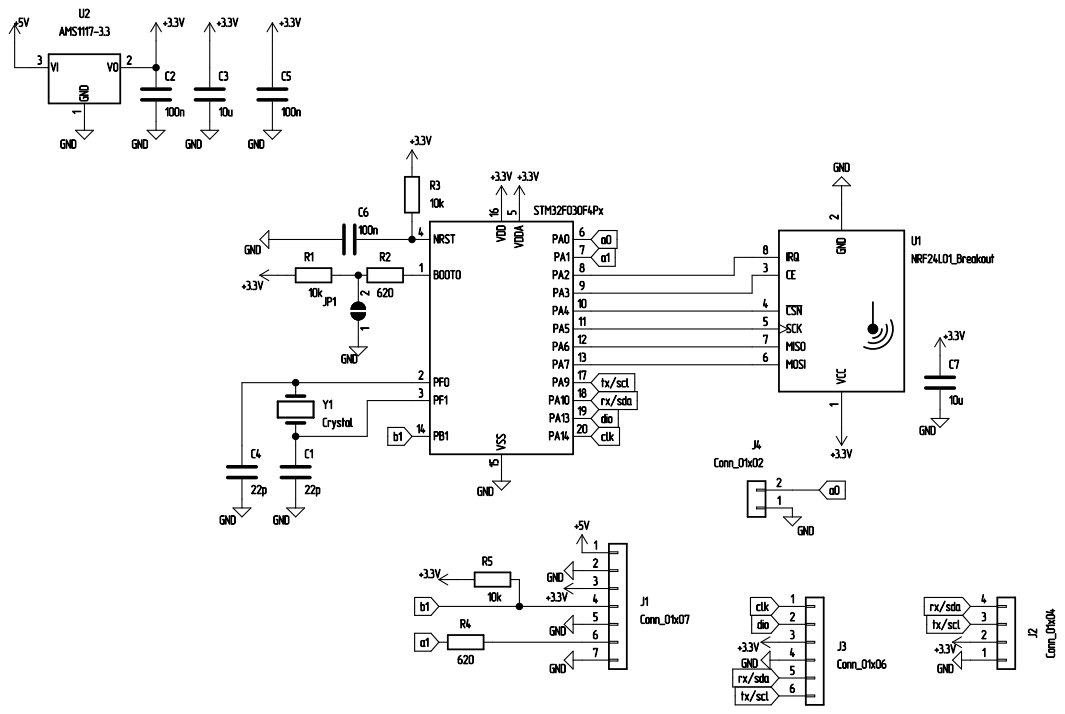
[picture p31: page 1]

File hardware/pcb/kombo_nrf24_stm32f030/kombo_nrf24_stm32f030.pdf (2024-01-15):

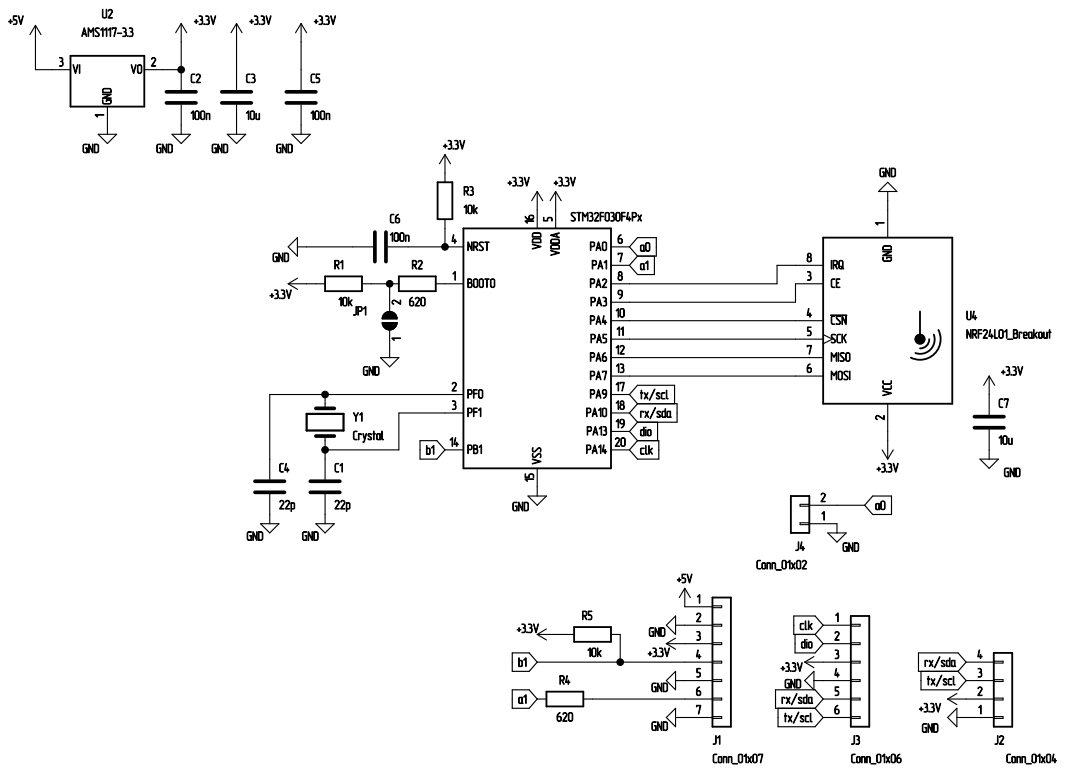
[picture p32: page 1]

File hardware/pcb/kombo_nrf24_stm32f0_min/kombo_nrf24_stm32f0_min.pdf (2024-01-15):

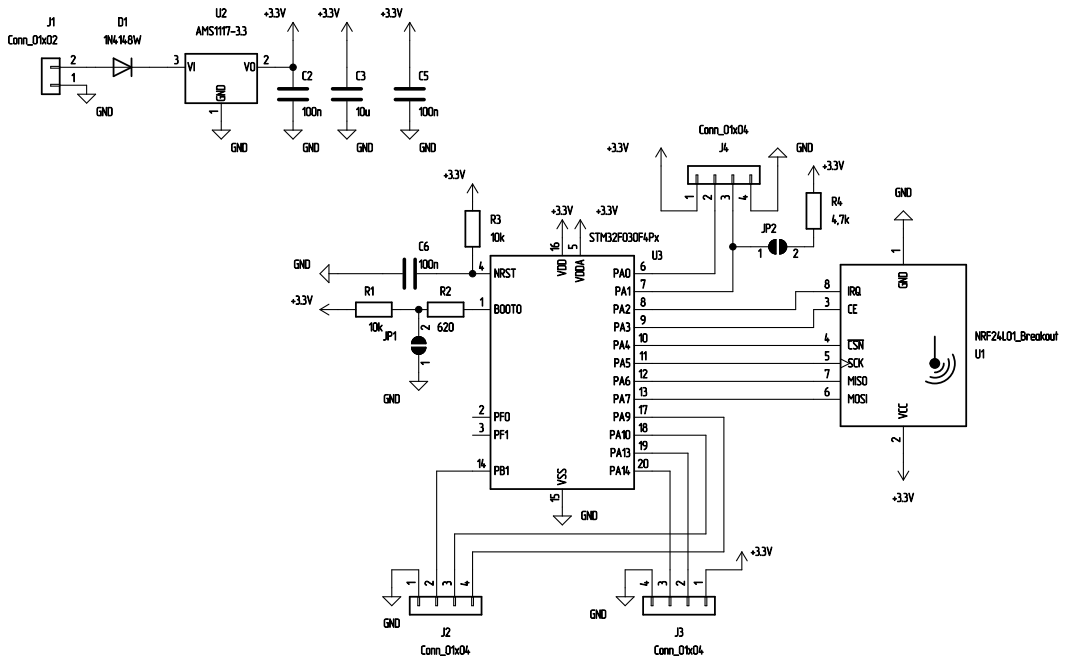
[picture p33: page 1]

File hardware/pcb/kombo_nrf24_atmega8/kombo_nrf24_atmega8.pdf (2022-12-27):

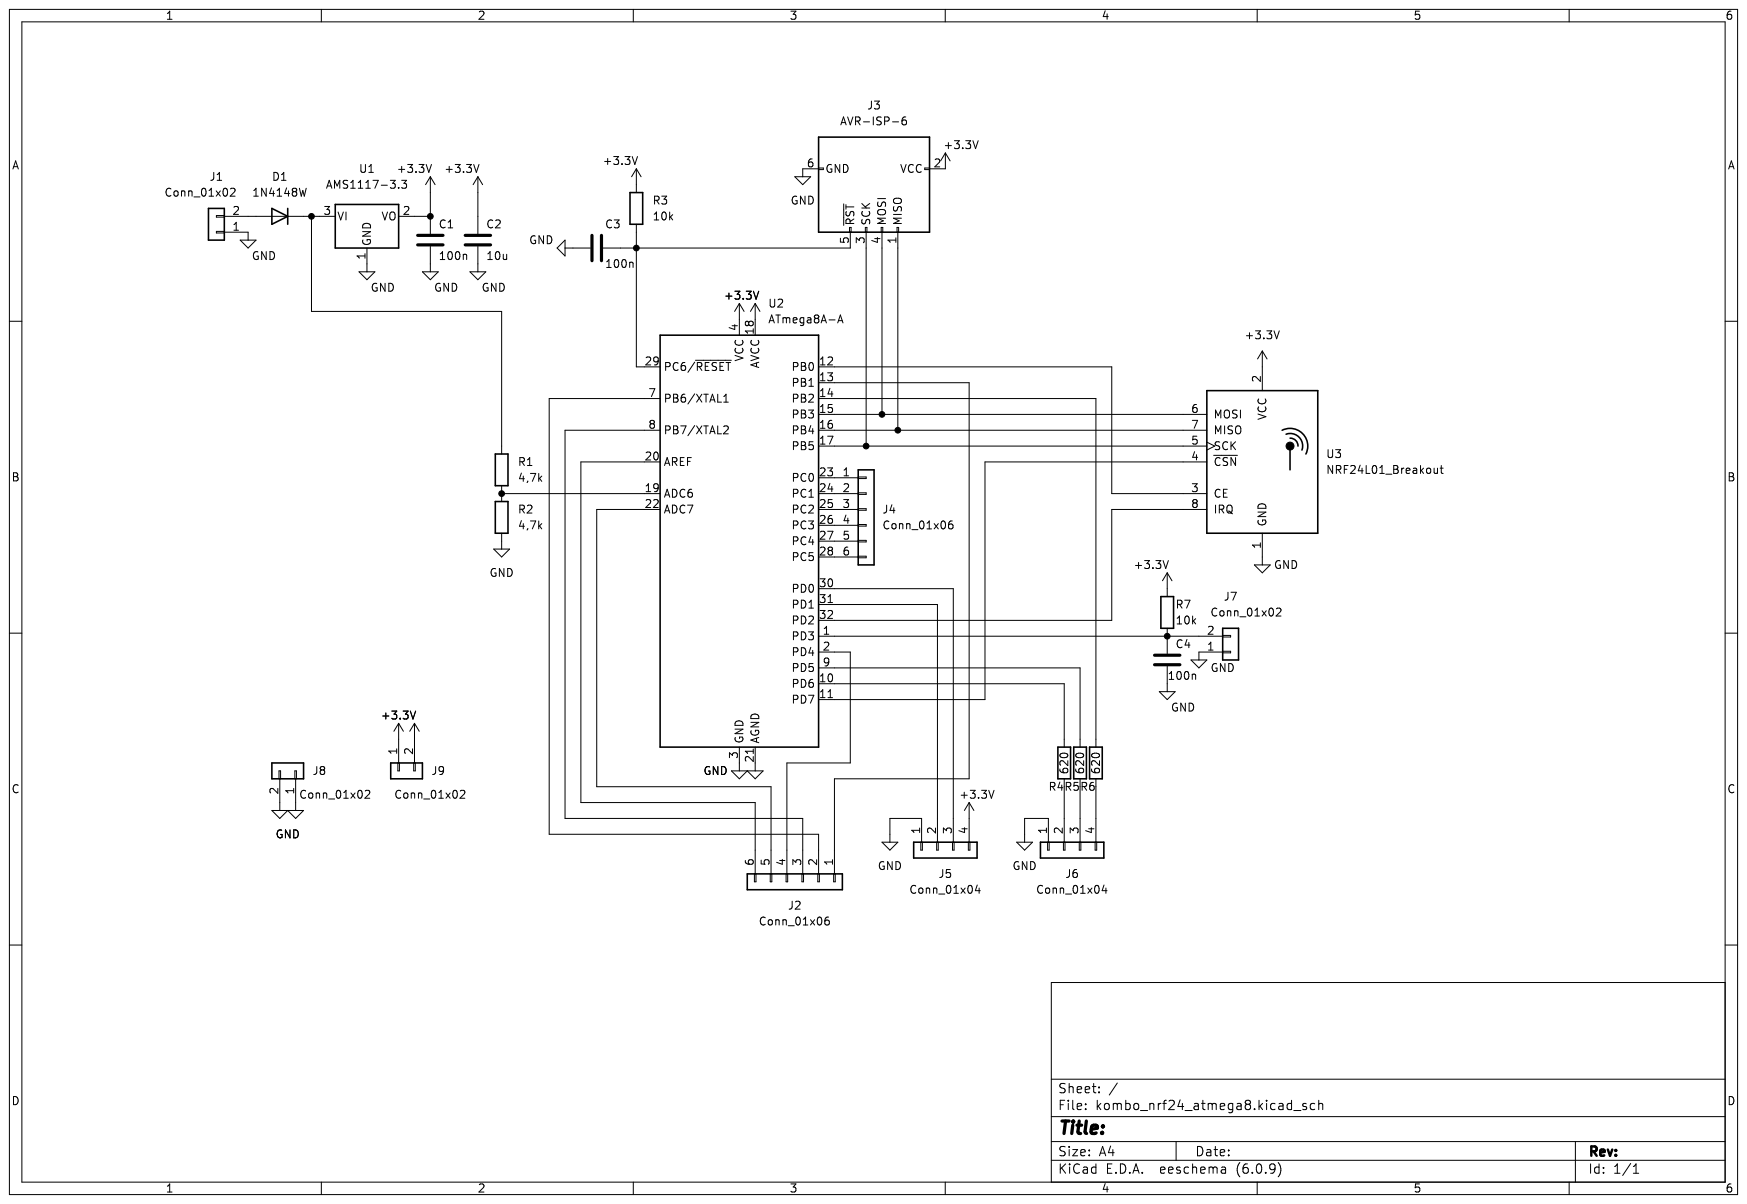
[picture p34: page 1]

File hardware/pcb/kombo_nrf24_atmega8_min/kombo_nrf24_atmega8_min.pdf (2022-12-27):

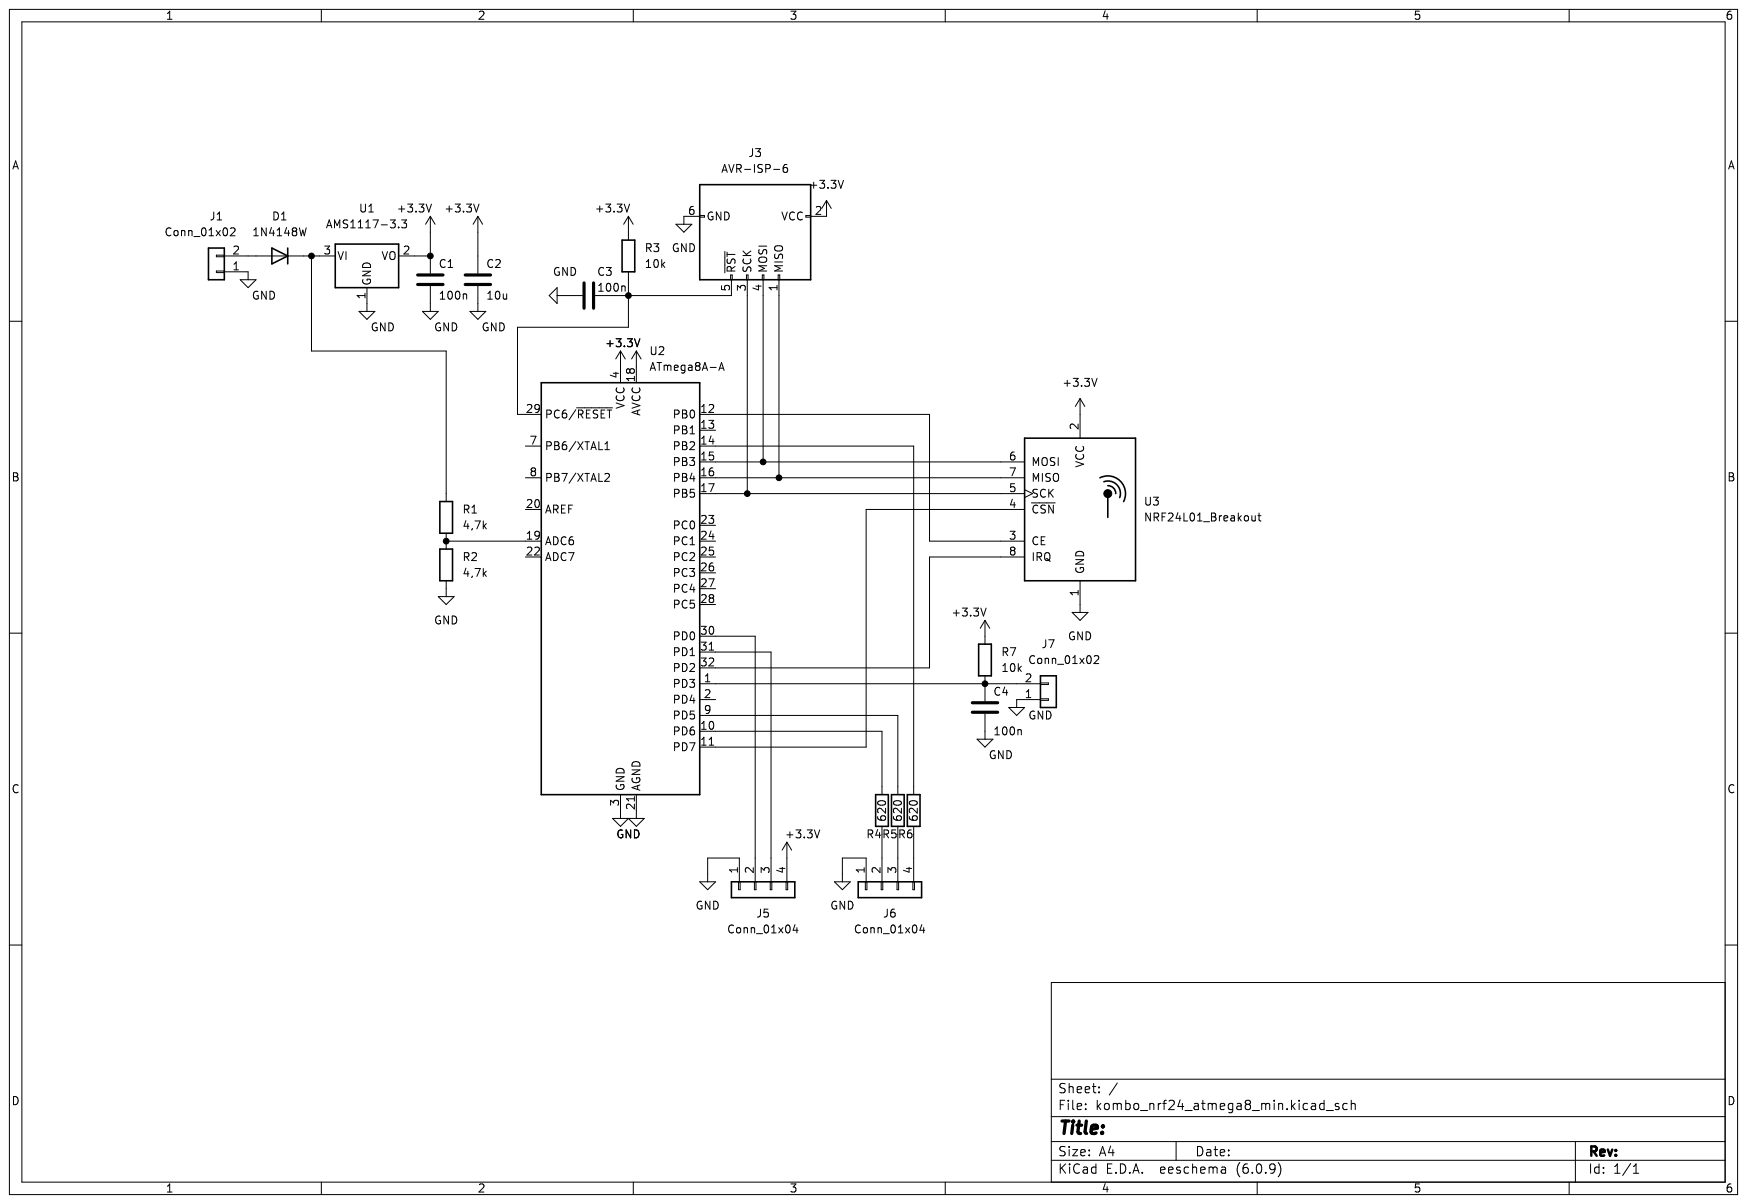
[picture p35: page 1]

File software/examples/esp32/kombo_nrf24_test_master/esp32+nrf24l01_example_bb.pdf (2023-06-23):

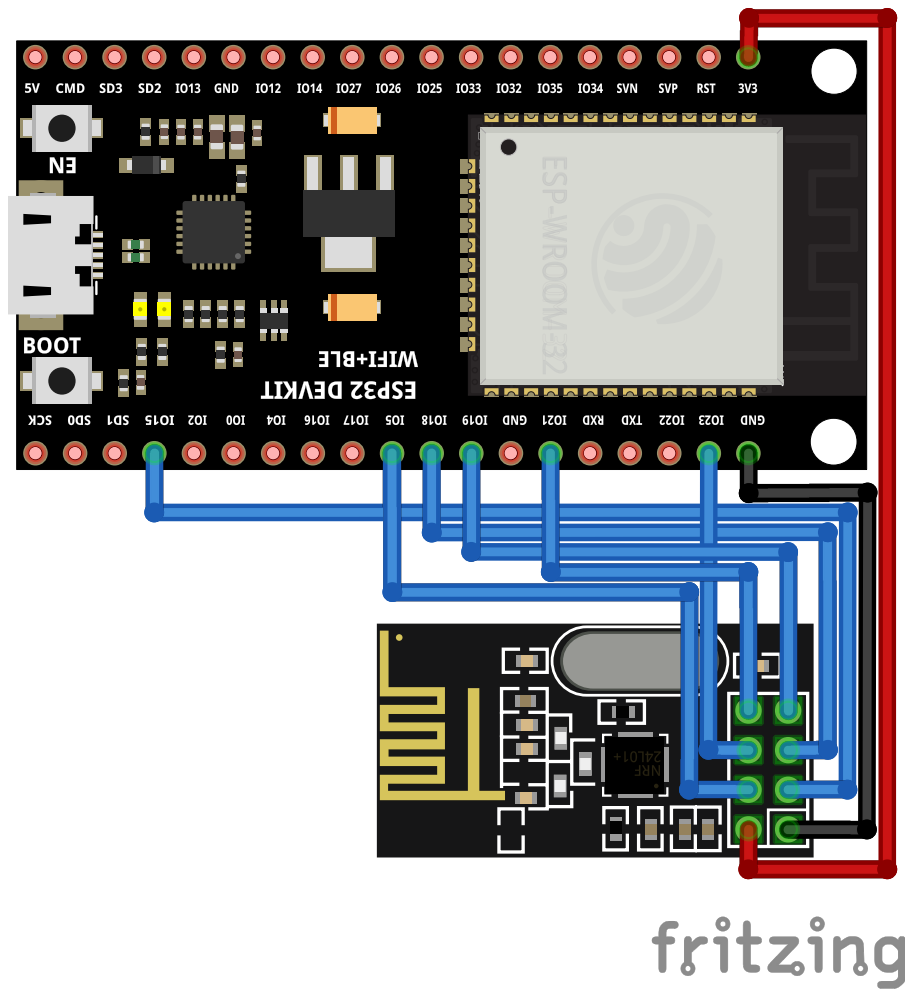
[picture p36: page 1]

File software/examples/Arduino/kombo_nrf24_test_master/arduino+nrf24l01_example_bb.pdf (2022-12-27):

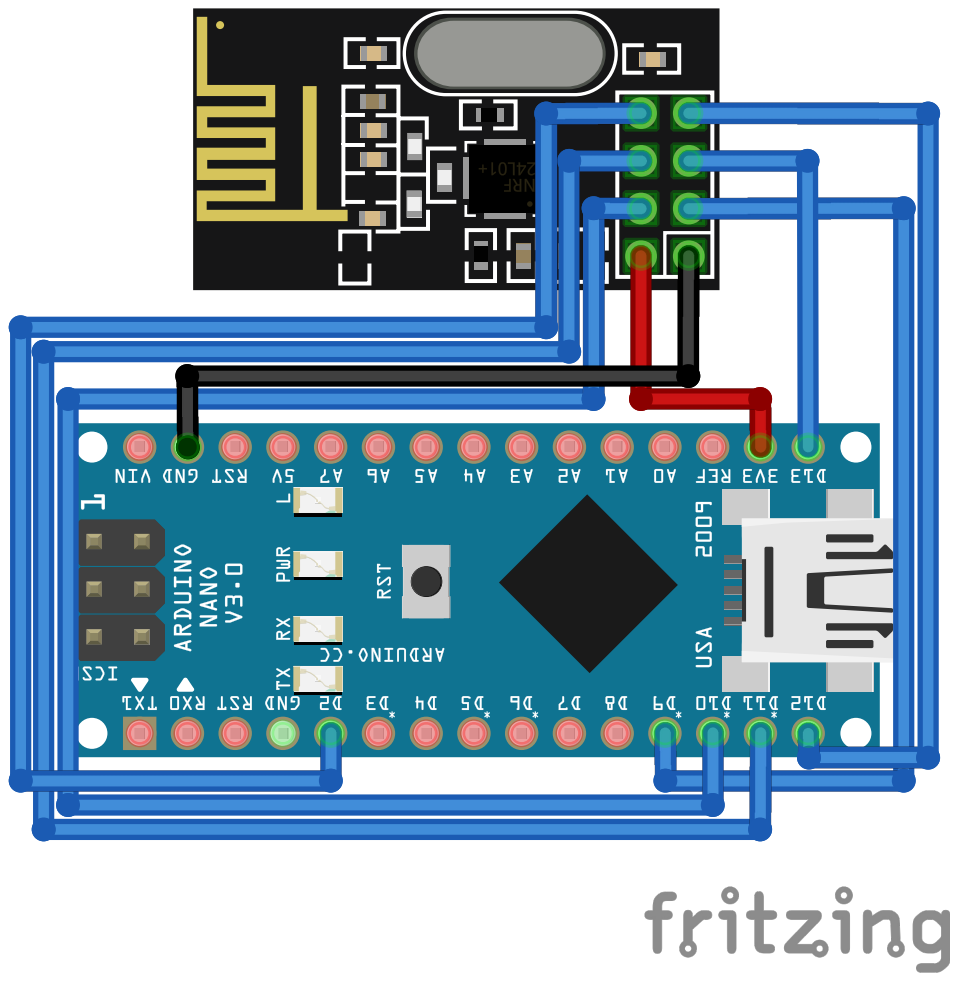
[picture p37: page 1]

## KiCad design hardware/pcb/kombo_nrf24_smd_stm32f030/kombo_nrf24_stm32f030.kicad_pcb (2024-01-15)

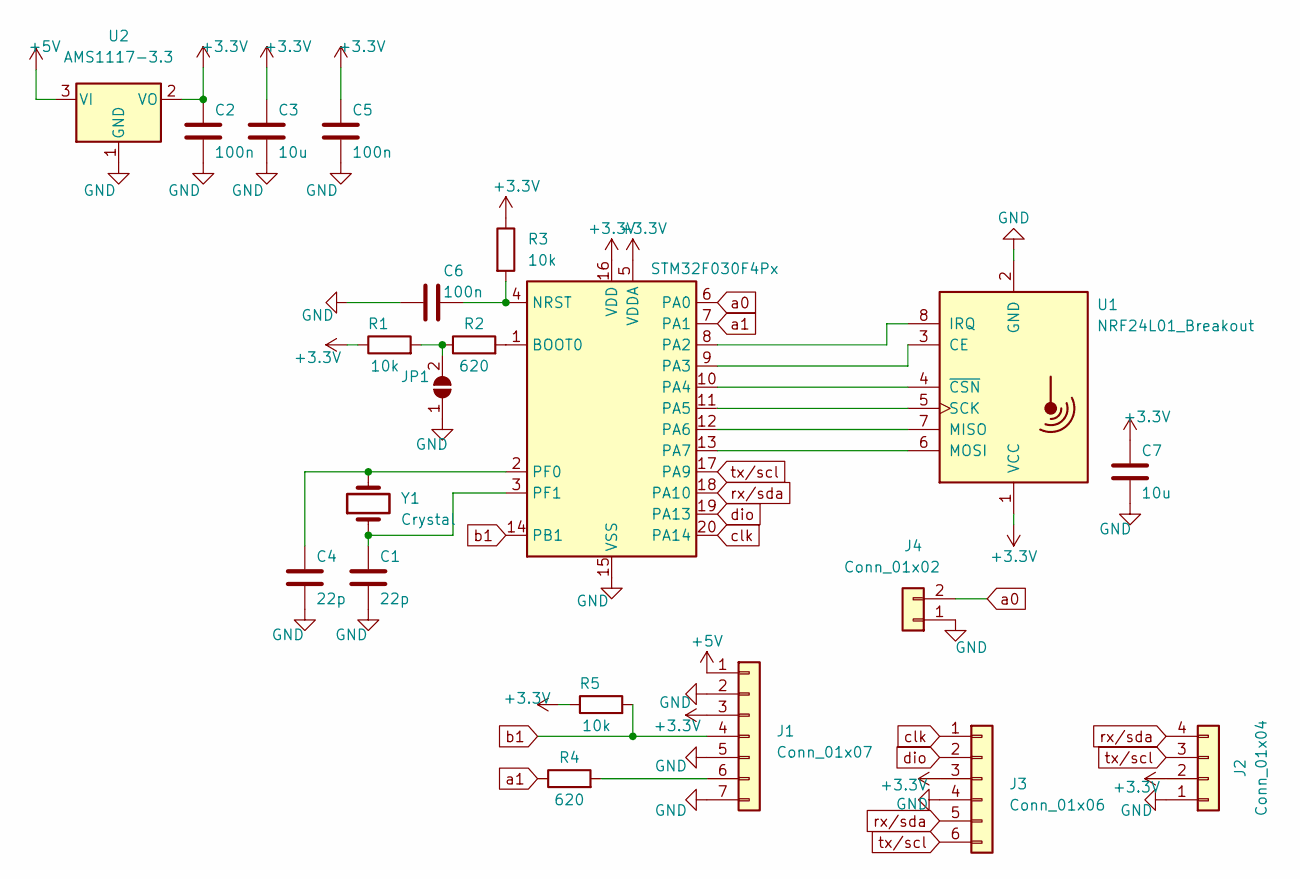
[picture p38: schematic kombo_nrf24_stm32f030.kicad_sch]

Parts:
C1, C4: 22p; C_0805_2012Metric_Pad1.18x1.45mm_HandSolder
C2, C5, C6: 100n; C_0805_2012Metric_Pad1.18x1.45mm_HandSolder
C3, C7: 10u; C_0805_2012Metric_Pad1.18x1.45mm_HandSolder
J1: Conn_01x07; PinHeader_1x07_P2.54mm_Vertical
J2: Conn_01x04; PinHeader_1x04_P2.54mm_Vertical
J3: Conn_01x06; PinHeader_1x06_P2.54mm_Vertical
J4: Conn_01x02; PinHeader_1x02_P2.54mm_Vertical
JP1: SolderJumper_2_Open; SolderJumper-2_P1.3mm_Open_TrianglePad1.0x1.5mm
R1, R3, R5: 10k; R_0805_2012Metric_Pad1.20x1.40mm_HandSolder
R2, R4: 620; R_0805_2012Metric_Pad1.20x1.40mm_HandSolder
U1: NRF24L01_Breakout; NRF24L01-Module-SMD
U2: AMS1117-3.3; SOT-223-3_TabPin2
U3: STM32F030F4Px; TSSOP-20_4.4x6.5mm_P0.65mm
Y1: Crystal; Crystal_HC49-U_Vertical

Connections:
+3V3: C2.1, C3.1, C5.1, C7.1, J1.3, J2.2, J3.3, R1.1, R3.1, R5.1, U1.1 (VCC), U2.2 (VO), U3.5 (VDDA), U3.16 (VDD)
+5V: J1.1, U2.3 (VI)
GND: C1.2, C2.2, C3.2, C4.2, C5.2, C6.2, C7.2, J1.2, J1.5, J1.7, J2.1, J3.4, J4.1, JP1.1 (A), U1.2 (GND), U2.1 (GND), U3.15 (VSS)
unnamed: J1.6, R4.2
unnamed: JP1.2 (B), R1.2, R2.1
unnamed: U1.3 (CE), U3.9 (PA3)
unnamed: U1.8 (IRQ), U3.8 (PA2)
unnamed: U1.7 (MISO), U3.12 (PA6)
unnamed: U1.6 (MOSI), U3.13 (PA7)
unnamed: U1.5 (SCK), U3.11 (PA5)
unnamed: U1.4 (~CSN), U3.10 (PA4)
unnamed: R2.2, U3.1 (BOOT0)
unnamed: C6.1, R3.2, U3.4 (NRST)
unnamed: C4.1, U3.2 (PF0), Y1.2
unnamed: C1.1, U3.3 (PF1), Y1.1
a0: J4.2, U3.6 (PA0)
but: J1.4, R5.2, U3.14 (PB1)
clk: J3.1, U3.20 (PA14)
dio: J3.2, U3.19 (PA13)
led: R4.1, U3.7 (PA1)
rx/sda: J2.4, J3.5, U3.18 (PA10)
tx/scl: J2.3, J3.6, U3.17 (PA9)

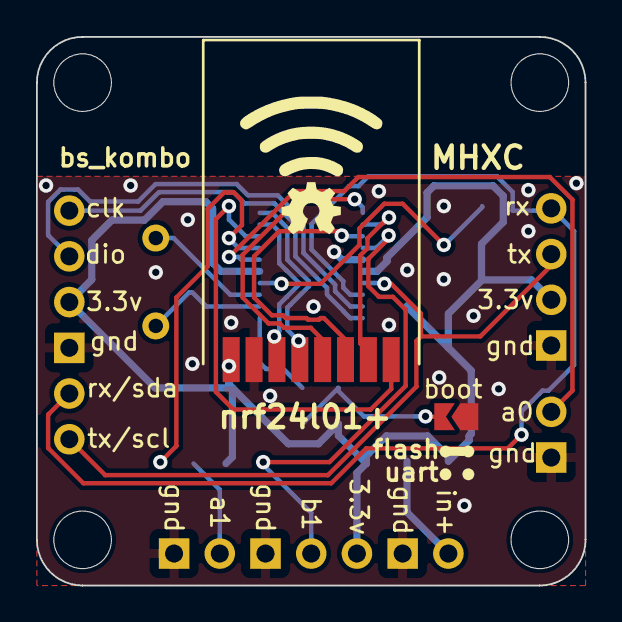
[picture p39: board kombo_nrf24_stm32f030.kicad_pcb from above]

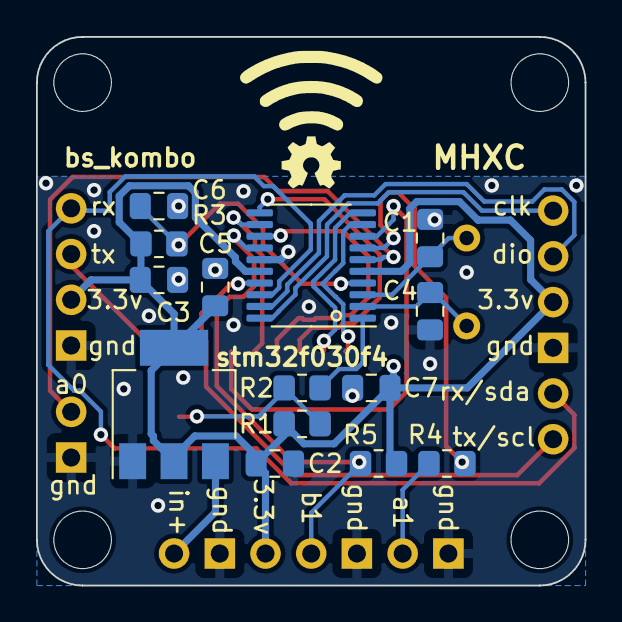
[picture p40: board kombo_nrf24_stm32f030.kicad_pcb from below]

Board: 2 copper layers, 30.5 x 30.5 mm, 21 parts (14 on the bottom side), 22 nets.

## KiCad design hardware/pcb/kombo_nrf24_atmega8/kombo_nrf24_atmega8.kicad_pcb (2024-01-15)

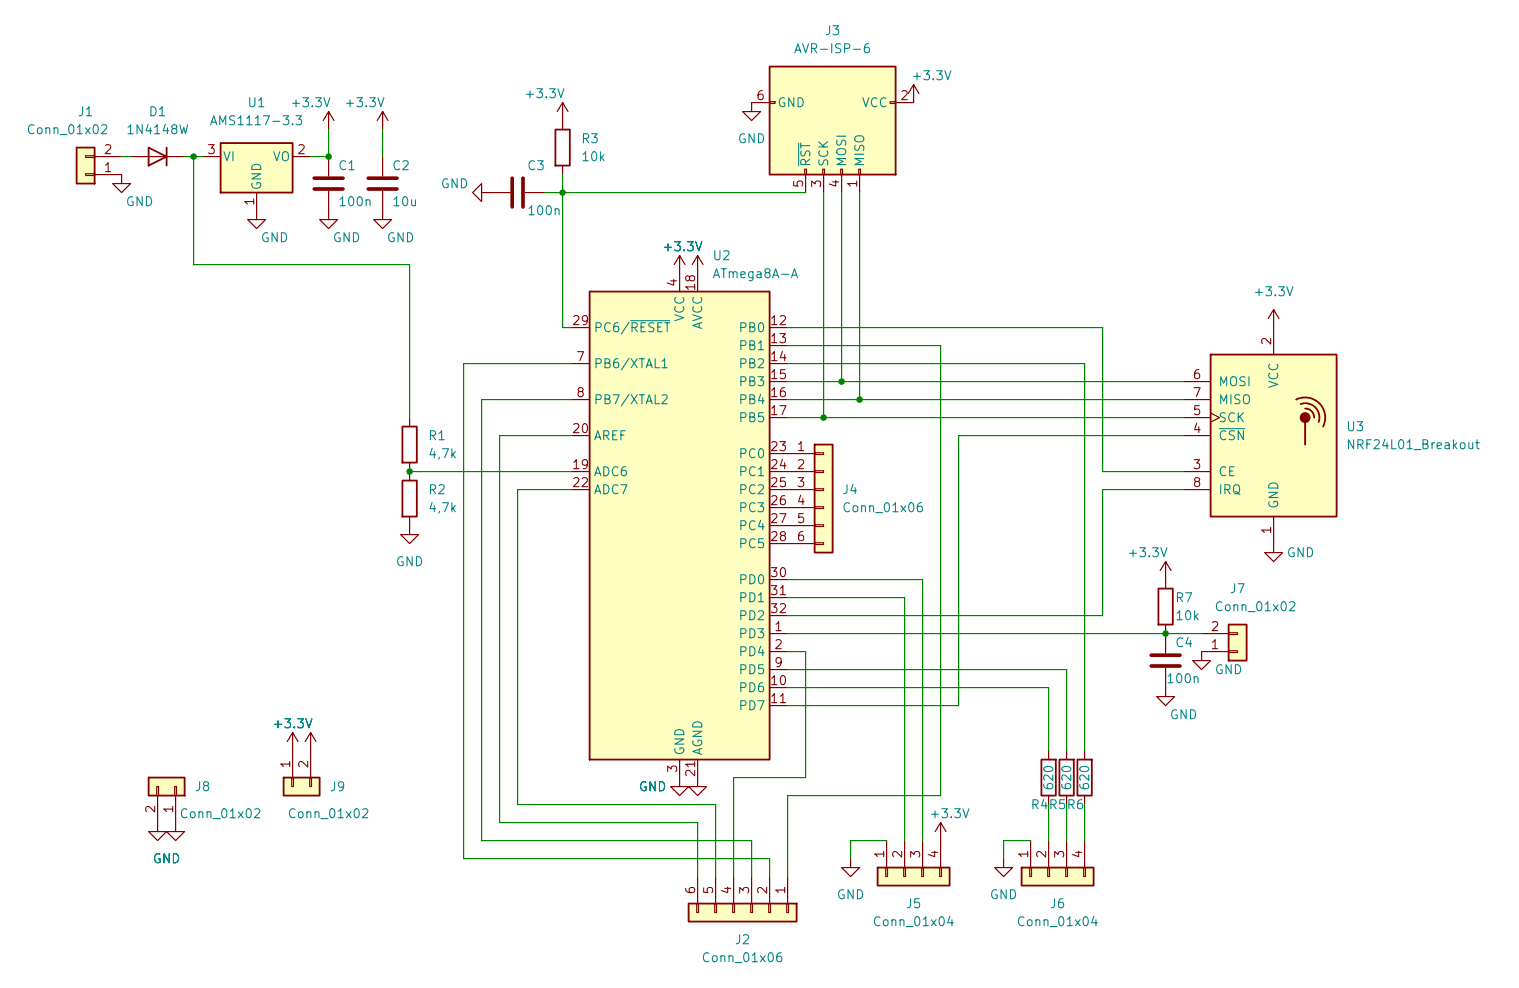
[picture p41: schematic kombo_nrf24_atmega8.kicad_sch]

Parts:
C1, C3, C4: 100n; C_0805_2012Metric
C2: 10u; C_0805_2012Metric
D1: 1N4148W; D_SOD-123
J1, J7, J8, J9: Conn_01x02; PinHeader_1x02_P2.54mm_Vertical
J2, J4: Conn_01x06; PinHeader_1x06_P2.54mm_Vertical
J3: AVR-ISP-6; PinHeader_2x03_P2.54mm_Vertical
J5, J6: Conn_01x04; PinHeader_1x04_P2.54mm_Vertical
R1, R2: 4,7k; R_0805_2012Metric
R3, R7: 10k; R_0805_2012Metric
R4, R5, R6: 620; R_0603_1608Metric
U1: AMS1117-3.3; SOT-223-3_TabPin2
U2: ATmega8A-A; TQFP-32_7x7mm_P0.8mm
U3: NRF24L01_Breakout; PinHeader_2x04_P2.54mm_Vertical

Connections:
+3V3: C1.1, C2.1, J3.2 (VCC), J5.4, J9.1, J9.2, R3.1, R7.1, U1.2 (VO), U2.4 (VCC), U2.6 (VCC), U2.18 (AVCC), U3.2 (VCC)
GND: C1.2, C2.2, C3.2, C4.2, J1.1, J3.6 (GND), J5.1, J6.1, J7.1, J8.1, J8.2, R2.2, U1.1 (GND), U2.3 (GND), U2.5 (GND), U2.21 (AGND), U3.1 (GND)
unnamed: C3.1, J3.5 (~RST), R3.2, U2.29 (PC6/~RESET)
unnamed: C4.1, J7.2, R7.2, U2.1 (PD3)
unnamed: D1.1 (K), R1.1, U1.3 (VI)
unnamed: D1.2 (A), J1.2
unnamed: J2.1, U2.13 (PB1)
unnamed: J2.2, U2.7 (PB6/XTAL1)
unnamed: J2.3, U2.8 (PB7/XTAL2)
unnamed: J2.4, U2.2 (PD4)
unnamed: J2.5, U2.22 (ADC7)
unnamed: J2.6, U2.20 (AREF)
unnamed: J3.1 (MISO), U2.16 (PB4), U3.7 (MISO)
unnamed: J3.3 (SCK), U2.17 (PB5), U3.5 (SCK)
unnamed: J3.4 (MOSI), U2.15 (PB3), U3.6 (MOSI)
unnamed: J4.1, U2.23 (PC0)
unnamed: J4.2, U2.24 (PC1)
unnamed: J4.3, U2.25 (PC2)
unnamed: J4.4, U2.26 (PC3)
unnamed: J4.5, U2.27 (PC4)
unnamed: J4.6, U2.28 (PC5)
unnamed: J5.2, U2.31 (PD1)
unnamed: J5.3, U2.30 (PD0)
unnamed: J6.2, R4.1
unnamed: J6.3, R5.1
unnamed: J6.4, R6.1
unnamed: R1.2, R2.1, U2.19 (ADC6)
unnamed: R4.2, U2.10 (PD6)
unnamed: R5.2, U2.9 (PD5)
unnamed: R6.2, U2.14 (PB2)
unnamed: U2.11 (PD7), U3.4 (~CSN)
unnamed: U2.12 (PB0), U3.3 (CE)
unnamed: U2.32 (PD2), U3.8 (IRQ)

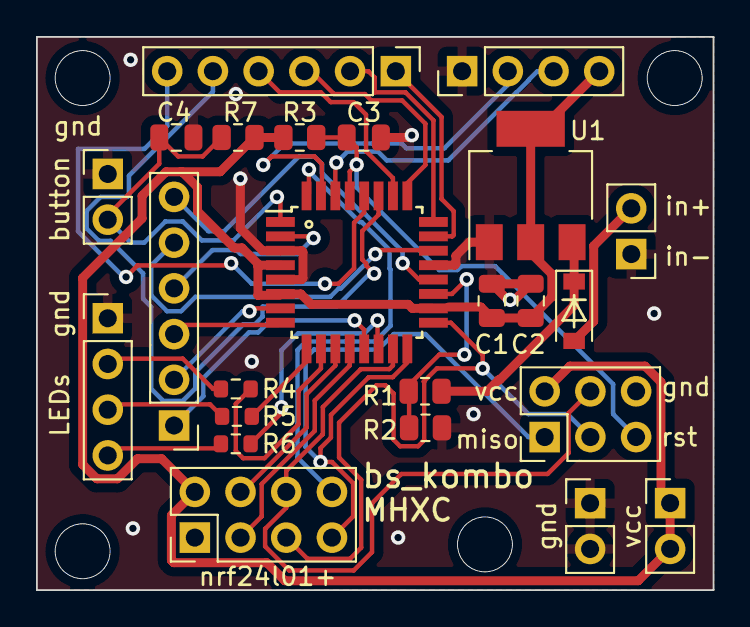
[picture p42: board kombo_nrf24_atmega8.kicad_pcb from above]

Board: 2 copper layers, 37.6 x 30.7 mm, 24 parts (0 on the bottom side), 33 nets.

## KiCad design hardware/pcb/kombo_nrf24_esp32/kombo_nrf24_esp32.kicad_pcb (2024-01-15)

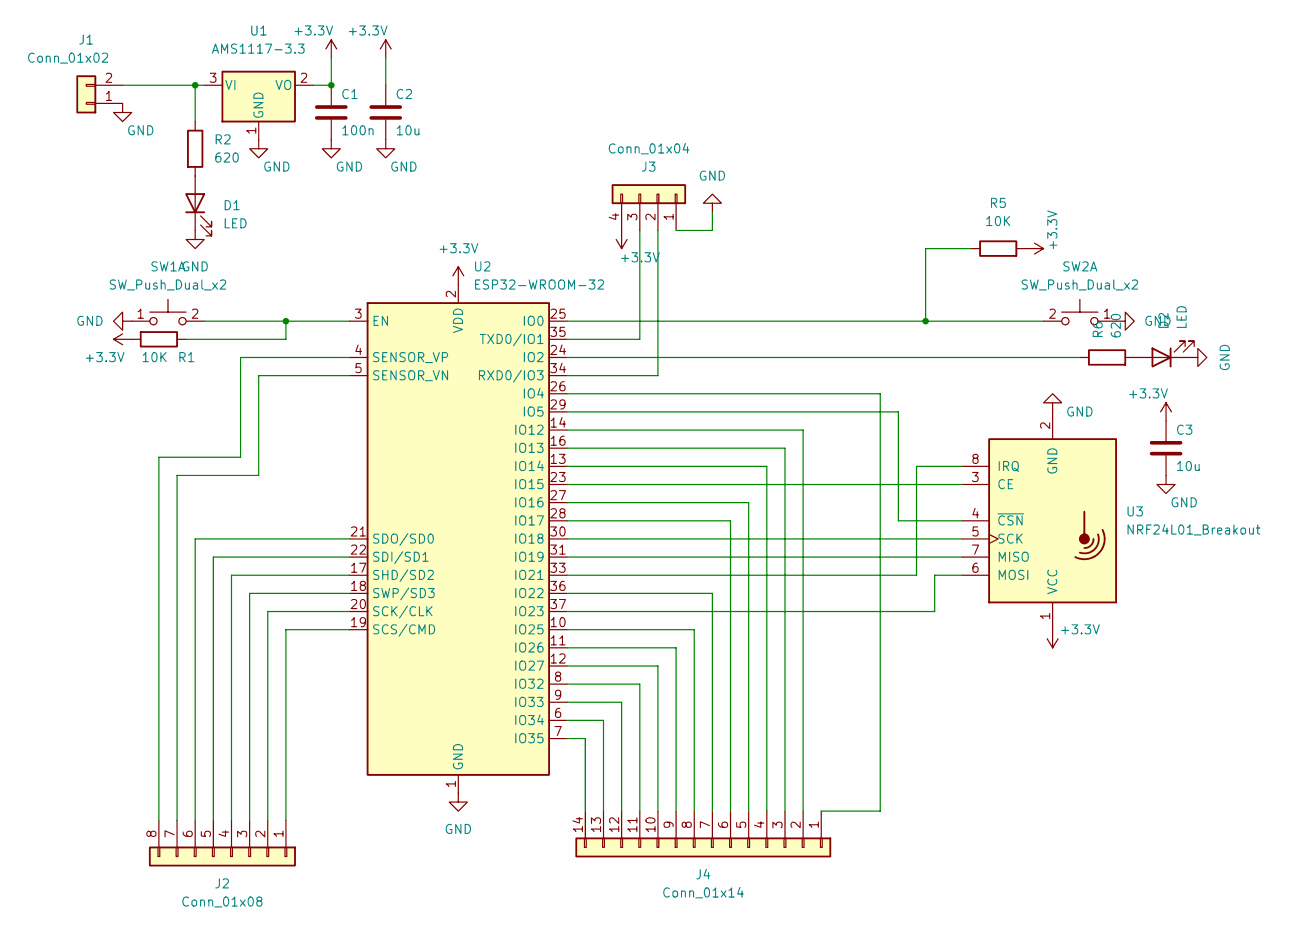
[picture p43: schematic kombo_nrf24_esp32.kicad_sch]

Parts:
C1: 100n; C_0805_2012Metric_Pad1.18x1.45mm_HandSolder
C2, C3: 10u; C_0805_2012Metric_Pad1.18x1.45mm_HandSolder
D1, D2: LED; LED_0805_2012Metric_Pad1.15x1.40mm_HandSolder
J1: Conn_01x02; PinHeader_1x02_P2.54mm_Vertical
J2: Conn_01x08; PinHeader_1x08_P2.54mm_Vertical
J3: Conn_01x04; PinHeader_1x04_P2.54mm_Vertical
J4: Conn_01x14; PinHeader_1x14_P2.54mm_Vertical
R1, R5: 10К; R_0805_2012Metric_Pad1.20x1.40mm_HandSolder
R2, R6: 620; R_0805_2012Metric_Pad1.20x1.40mm_HandSolder
SW1, SW2: SW_Push_Dual_x2; SW_PUSH_6mm_H4.3mm
U1: AMS1117-3.3; SOT-223-3_TabPin2
U2: ESP32-WROOM-32
U3: NRF24L01_Breakout; NRF24L01-SMD

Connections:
+3.3V: C1.1, C2.1, C3.1, J3.4, R1.2, R5.2, U1.2 (VO), U2.2 (VDD), U3.1 (VCC)
GND: C1.2, C2.2, C3.2, D1.1 (K), D2.1 (K), J1.1, J3.1, SW1.1 (C), SW2.1 (C), U1.1 (GND), U2.1 (GND), U2.15 (GND), U2.38 (GND), U2.39 (GND), U3.2 (GND)
unnamed: D1.2 (A), R2.2
unnamed: D2.2 (A), R6.2
unnamed: J1.2, R2.1, U1.3 (VI)
unnamed: J2.1, U2.19 (SCS/CMD)
unnamed: J2.2, U2.20 (SCK/CLK)
unnamed: J2.3, U2.18 (SWP/SD3)
unnamed: J2.4, U2.17 (SHD/SD2)
unnamed: J2.5, U2.22 (SDI/SD1)
unnamed: J2.6, U2.21 (SDO/SD0)
unnamed: J2.7, U2.5 (SENSOR_VN)
unnamed: J2.8, U2.4 (SENSOR_VP)
unnamed: J3.2, U2.34 (RXD0/IO3)
unnamed: J3.3, U2.35 (TXD0/IO1)
unnamed: J4.1, U2.26 (IO4)
unnamed: J4.2, U2.14 (IO12)
unnamed: J4.3, U2.16 (IO13)
unnamed: J4.4, U2.13 (IO14)
unnamed: J4.5, U2.27 (IO16)
unnamed: J4.6, U2.28 (IO17)
unnamed: J4.7, U2.36 (IO22)
unnamed: J4.8, U2.10 (IO25)
unnamed: J4.9, U2.11 (IO26)
unnamed: J4.10, U2.12 (IO27)
unnamed: J4.11, U2.8 (IO32)
unnamed: J4.12, U2.9 (IO33)
unnamed: J4.13, U2.6 (IO34)
unnamed: J4.14, U2.7 (IO35)
unnamed: R1.1, SW1.2 (D), U2.3 (EN)
unnamed: R5.1, SW2.2 (D), U2.25 (IO0)
unnamed: R6.1, U2.24 (IO2)
unnamed: U2.29 (IO5), U3.4 (~CSN)
unnamed: U2.23 (IO15), U3.3 (CE)
unnamed: U2.30 (IO18), U3.5 (SCK)
unnamed: U2.31 (IO19), U3.7 (MISO)
unnamed: U2.33 (IO21), U3.8 (IRQ)
unnamed: U2.37 (IO23), U3.6 (MOSI)

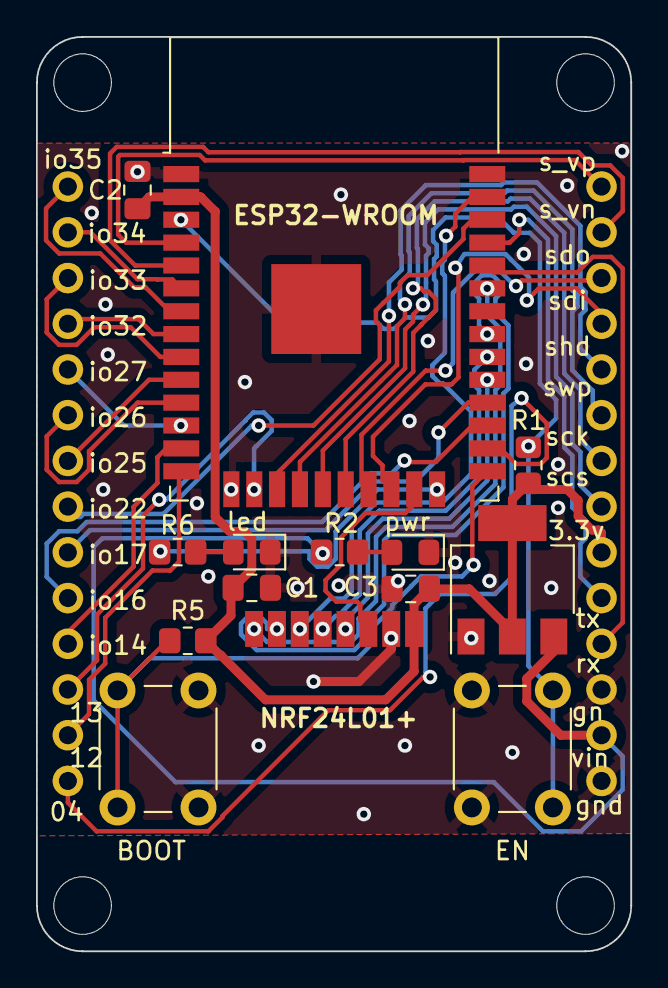
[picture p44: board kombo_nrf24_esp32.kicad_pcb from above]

Board: 2 copper layers, 33.0 x 50.8 mm, 18 parts (0 on the bottom side), 38 nets.

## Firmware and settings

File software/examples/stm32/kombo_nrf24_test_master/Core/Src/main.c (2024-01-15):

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
/* Includes ------------------------------------------------------------------*/
#include "main.h"


/* USER CODE BEGIN PV */
//объявляем переменные и массивы
char str[STRING_SIZE] = {0};						//буфер для вывода в порт
uint8_t slave_counter = 0;							//счетчик ведомых
uint8_t slave_addrs[] = ADRESS_LIST;		//массив адресов ведомых
//внешние переменные и массивы
extern volatile uint8_t f_rx, f_tx;			//флаги приема и передачи
extern uint8_t tx_buf[TX_PLOAD_WIDTH];	//буфер передачи
extern uint8_t rx_buf[TX_PLOAD_WIDTH];	//буфер приема
/* USER CODE END PV */

void SystemClock_Config(void);
static void MX_GPIO_Init(void);
static void MX_IWDG_Init(void);
static void MX_SPI1_Init(void);
static void MX_USART1_UART_Init(void);
static void MX_TIM1_Init(void);
/* USER CODE BEGIN 0 */
//Процедура вывода в порт данных из регистров радиомодуля
void nrf_info_print(void)
{
	uint8_t buf[TX_ADR_WIDTH] = {0};				//буфер для чтения адресов модуля
	uint8_t dt_reg = 0;											//переменная для чтения значения регистра
	
	dt_reg = nrf24_read_reg(CONFIG);							//читаем регистр CONFIG
	sprintf(str, "CONFIG: 0x%02X\r\n", dt_reg);		//
	usart_print(str);															//выводим данные в порт
	dt_reg = nrf24_read_reg(EN_AA);								//читаем регистр EN_AA
	sprintf(str, "EN_AA: 0x%02X\r\n", dt_reg);		//
	usart_print(str);															//выводим данные в порт
	dt_reg = nrf24_read_reg(EN_RXADDR);						//читаем регистр EN_RXADDR
	sprintf(str, "EN_RXADDR: 0x%02X\r\n", dt_reg);//
	usart_print(str);															//выводим данные в порт
	dt_reg = nrf24_read_reg(STATUS);							//читаем регистр STATUS
	sprintf(str, "STATUS: 0x%02X\r\n", dt_reg);		//
	usart_print(str);															//выводим данные в порт
	dt_reg = nrf24_read_reg(RF_SETUP);						//читаем регистр RF_SETUP
	sprintf(str, "RF_SETUP: 0x%02X\r\n", dt_reg);	//
	usart_print(str);															//выводим данные в порт
	nrf24_read_buf(TX_ADDR,buf,3);								//читаем буфер TX_ADDR
	sprintf(str, "TX_ADDR: 0x%02X, 0x%02X, 0x%02X\r\n", buf[0], buf[1], buf[2]);
	usart_print(str);															//выводим данные в порт
	nrf24_read_buf(RX_ADDR_P1,buf,3);							//читаем буфер RX_ADDR_P1
	sprintf(str, "RX_ADDR: 0x%02X, 0x%02X, 0x%02X\r\n", buf[0], buf[1], buf[2]);
	usart_print(str);															//выводим данные в порт
}

//Процедура моргания светодиодом
void blink_led(uint8_t blink_counter)
{
	while (blink_counter)		//пока счетчик не равен 0
	{
		LED_ON();							//включаем светодиод
		LL_mDelay(50);				//ждем
		LED_OFF();						//выключаем светодиод
		LL_mDelay(50);				//ждем
		blink_counter--;			//декрементируем счетчик
	}
}

//Процедура приема радиомодуля
void nrf24l01_receive(void)
{
	if(f_rx)	//если флаг приема поднят (флаг поднимается по внешнему прерыванию от радиомодуля)
	{
		/*ДЕЙСТВИЯ ПО ПОЛУЧЕНИЮ ОТВЕТА ОТ ВЕДОМОГО УСТРОЙСТВА*/
		
		//тут можно прописать действия ведущего устройства при получении
		//ответа от одного из ведомых мы определяем с какого конкретно адреса пришел ответ,
		//формируется и отправляется ответ на запрос и сообщаем об этом в порт
		
		//цикл по всем ведомым устройствам
		for (uint8_t i = 0; i < NUM_OF_SLAVES; i++)
		{	//если найден принятый адрес
			if (rx_buf[0] == slave_addrs[i]) 	
			{//формируем строку для вывода в порт
				sprintf(str,"Adress 0x%02X\t data: %d\r\n",rx_buf[0],rx_buf[1]);			
				usart_print(str);	//отправляем строку в порт
			}
		}
		f_rx = 0;					//опускаем флаг приема
	}
}
/* USER CODE END 0 */

/**
  * @brief  The application entry point.
  * @retval int
  */
int main(void)
{
  /* MCU Configuration--------------------------------------------------------*/

  /* Reset of all peripherals, Initializes the Flash interface and the Systick. */

  LL_APB1_GRP2_EnableClock(LL_APB1_GRP2_PERIPH_SYSCFG);
  LL_APB1_GRP1_EnableClock(LL_APB1_GRP1_PERIPH_PWR);

  /* System interrupt init*/
  /* SysTick_IRQn interrupt configuration */
  NVIC_SetPriority(SysTick_IRQn, 3);

  /* Configure the system clock */
  SystemClock_Config();

  /* Initialize all configured peripherals */
  MX_GPIO_Init();
  MX_IWDG_Init();
  MX_SPI1_Init();
  MX_USART1_UART_Init();
  MX_TIM1_Init();
  /* USER CODE BEGIN 2 */

	//Включаем SPI
	LL_SPI_Enable(SPI1);
	//Включаем внешнее прерывание
	LL_EXTI_EnableIT_0_31(LL_EXTI_LINE_2);
	LL_EXTI_EnableFallingTrig_0_31(LL_EXTI_LINE_2);

  usart_init(0);					//инициализируем USART
	usart_println("start");	//отправляем стартовую строку в порт
	nrf24_init();						//инициализируем радиомодуль
	nrf_info_print();
	
  /* USER CODE END 2 */

  /* Infinite loop */
  /* USER CODE BEGIN WHILE */
  while (1)
  {
		//отправляем запрос по очередному адресу
		tx_buf[0] = slave_addrs[slave_counter];	//записываем в буфер очередной адрес
		
		nrf24_send(tx_buf);						//отправляем посылку в эфир
		//запрос содержит только адрес устройства, но может содержать другую информацию размером до 32 байт
		
		slave_counter++;						//переходим к следующему адресу
		if (slave_counter == NUM_OF_SLAVES)		//если дошли до последнего элемента
		{
			slave_counter = 0;					//обнуляем счетчик
		}
		
		LL_mDelay(2);							//задержка
		
		//задержка необходима, чтобы ведомое устройство успело получить запрос, отправить ответ, 
		//а данное ведущее устройство успело получить и обработать отет на запрос, прежде чем 
		//переходить к отправке следующего
		
		//для достижения максимального быстродействия величину задержки необходимо подбирать наименьшей
		//экспериментально с учетом времени, затрачиваемого на остальные действия микроконтроллера
		
		nrf24l01_receive();		//обрабатываем прием радиомодуля

    /* USER CODE END WHILE */

    /* USER CODE BEGIN 3 */
		LL_IWDG_ReloadCounter(IWDG);//сбрасываем сторожевой таймер
		
  }
  /* USER CODE END 3 */
}

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
/* USER CODE BEGIN 4 */
void TIM1_Callback(void)
{
	if(LL_TIM_IsActiveFlag_UPDATE(TIM1))			//если флаг прерывания таймера поднят
	{
		LL_TIM_ClearFlag_UPDATE(TIM1);					//опускаем флаг прерывания
	}
}


/* USER CODE END 4 */
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


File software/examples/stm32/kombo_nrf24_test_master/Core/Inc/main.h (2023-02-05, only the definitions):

#define IRQ_Pin LL_GPIO_PIN_2
#define IRQ_GPIO_Port GPIOA
#define IRQ_EXTI_IRQn EXTI2_3_IRQn
#define CE_Pin LL_GPIO_PIN_3
#define CE_GPIO_Port GPIOA
#define CSN_Pin LL_GPIO_PIN_4
#define CSN_GPIO_Port GPIOA
#define LED_Pin LL_GPIO_PIN_1
#define LED_GPIO_Port GPIOB
#define NVIC_PRIORITYGROUP_0         ((uint32_t)0x00000007) /*!< 0 bit  for pre-emption priority,
#define NVIC_PRIORITYGROUP_1         ((uint32_t)0x00000006) /*!< 1 bit  for pre-emption priority,
#define NVIC_PRIORITYGROUP_2         ((uint32_t)0x00000005) /*!< 2 bits for pre-emption priority,
#define NVIC_PRIORITYGROUP_3         ((uint32_t)0x00000004) /*!< 3 bits for pre-emption priority,
#define NVIC_PRIORITYGROUP_4         ((uint32_t)0x00000003) /*!< 4 bits for pre-emption priority,
#define STM32_LL					//stm32, библиотека LL
#define NUM_OF_SLAVES 	20			//количество ведомых устройств
#define ADRESS_LIST		{0x00, 0x01, 0x02, 0x03, 0x04, 0x05, 0x06, 0x07, 0x08, 0x09, 0x0A, 0x0B, 0x0C, 0x0D, 0x0E, 0x0F, 0x10, 0x11, 0x12, 0x13}
#define STRING_SIZE		64	//размер строк

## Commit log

2023-01-10 10.01.2023
    Исправлена кодировка комментариев
    [kombo_nrf24.h, main.h]
2023-01-12 12.01.2023
    Откорректирован вывод отрицательных температур в программе примера базы метеодатчиков, обновлены исполнительные файлы
2023-02-05 Обновление 05.02.2023
    Добавлены примеры для микроконтроллеров stm32.
    Добавлен проект платы минимального размера для stm32f030f4p6
    [bom.csv, designators.csv, kombo_nrf24_stm32f0_min.kicad_pcb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]
2023-06-23 update 23.06.2023
    Добавлен вариант с esp32
    Исправлены ошибки
    [bom.csv, bottom_90_21.11.2022.stl, designators.csv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]
2024-01-15 15/01/2024
    ✅ - обновлена библиотека работы с модулем nrf24l01+
    ✅ - добавлена библиотека работы с адресными светодиодами ws2812
    ✅ - обновлены файлы печатных плат
    ✅ - добавлены файлы печатных плат микроконтроллера stm32f030f4p6 c nrf24l01+
    [bom.csv, designators.csv, kombo_nrf24_atmega8.kicad_pcb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]
